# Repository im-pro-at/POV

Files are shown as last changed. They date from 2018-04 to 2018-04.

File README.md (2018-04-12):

# POV
A 131*131*12bit 16FPS POV Display

Youtube Video:

Youtube Video (http://www.youtube.com/watch?v=CScyjsmp5GI "POV")

3D Animation:

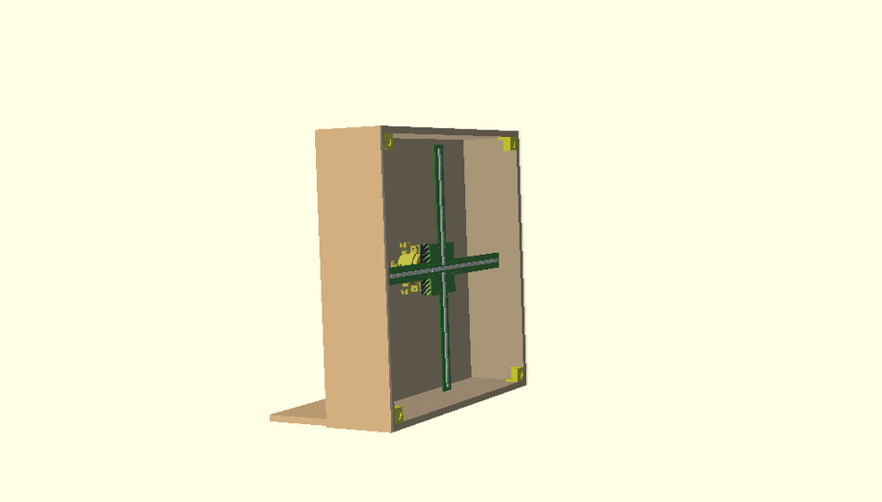
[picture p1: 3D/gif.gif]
3d


More Information: [Webside](https://im-pro.at/index.php/projekte/2018-pov)

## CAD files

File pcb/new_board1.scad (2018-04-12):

module new_board1(){
	board_thickness = 1.600000;
	eta = 0.1;
	board_size = [66.040000,71.120000,board_thickness];
	fn = 18;
	board_origin = [0.000000,0.000000];
	union(){
		color("green")difference(){
			translate(board_origin)cube(board_size); //Board
			translate([25.400,43.180,-0.1])cylinder(r=1.600000, h=board_thickness+0.2,$fn=fn); //Hole
			translate([40.640,43.180,-0.1])cylinder(r=1.600000, h=board_thickness+0.2,$fn=fn); //Hole
			translate([40.640,27.940,-0.1])cylinder(r=1.600000, h=board_thickness+0.2,$fn=fn); //Hole
			translate([25.400,27.940,-0.1])cylinder(r=1.600000, h=board_thickness+0.2,$fn=fn); //Hole
			translate([60.960,43.180,-0.1])cylinder(r=1.600000, h=board_thickness+0.2,$fn=fn); //Hole
			translate([60.960,27.940,-0.1])cylinder(r=1.600000, h=board_thickness+0.2,$fn=fn); //Hole
			translate([5.080,43.180,-0.1])cylinder(r=1.600000, h=board_thickness+0.2,$fn=fn); //Hole
			translate([5.080,27.940,-0.1])cylinder(r=1.600000, h=board_thickness+0.2,$fn=fn); //Hole
			translate([25.400,5.080,-0.1])cylinder(r=1.600000, h=board_thickness+0.2,$fn=fn); //Hole
			translate([40.640,5.080,-0.1])cylinder(r=1.600000, h=board_thickness+0.2,$fn=fn); //Hole
			translate([25.400,66.040,-0.1])cylinder(r=1.600000, h=board_thickness+0.2,$fn=fn); //Hole
			translate([40.640,66.040,-0.1])cylinder(r=1.600000, h=board_thickness+0.2,$fn=fn); //Hole
			translate([50.800,20.320,-eta])cylinder(r=0.508000, h=board_thickness+eta*2,$fn=fn); //317TS 1
			translate([53.340,20.320,-eta])cylinder(r=0.508000, h=board_thickness+eta*2,$fn=fn); //317TS 2
			translate([55.880,20.320,-eta])cylinder(r=0.508000, h=board_thickness+eta*2,$fn=fn); //317TS 3
			translate([51.435,68.580,-eta])cylinder(r=0.457200, h=board_thickness+eta*2,$fn=fn); //06P 1
			translate([53.975,68.580,-eta])cylinder(r=0.457200, h=board_thickness+eta*2,$fn=fn); //06P 2
			translate([56.515,68.580,-eta])cylinder(r=0.457200, h=board_thickness+eta*2,$fn=fn); //06P 3
			translate([59.055,68.580,-eta])cylinder(r=0.457200, h=board_thickness+eta*2,$fn=fn); //06P 4
			translate([61.595,68.580,-eta])cylinder(r=0.457200, h=board_thickness+eta*2,$fn=fn); //06P 5
			translate([64.135,68.580,-eta])cylinder(r=0.457200, h=board_thickness+eta*2,$fn=fn); //06P 6
			translate([45.720,17.780,-eta])cylinder(r=0.457200, h=board_thickness+eta*2,$fn=fn); //02P 1
			translate([45.720,20.320,-eta])cylinder(r=0.457200, h=board_thickness+eta*2,$fn=fn); //02P 2
			translate([45.720,15.240,-eta])cylinder(r=0.406400, h=board_thickness+eta*2,$fn=fn); //DCDC GND1
			translate([45.720,12.700,-eta])cylinder(r=0.406400, h=board_thickness+eta*2,$fn=fn); //DCDC GND2
			translate([64.120,15.240,-eta])cylinder(r=0.406400, h=board_thickness+eta*2,$fn=fn); //DCDC GND3
			translate([64.120,12.700,-eta])cylinder(r=0.406400, h=board_thickness+eta*2,$fn=fn); //DCDC GND4
			translate([45.720,4.640,-eta])cylinder(r=0.406400, h=board_thickness+eta*2,$fn=fn); //DCDC VIN1
			translate([45.720,2.140,-eta])cylinder(r=0.406400, h=board_thickness+eta*2,$fn=fn); //DCDC VIN2
			translate([64.120,4.640,-eta])cylinder(r=0.406400, h=board_thickness+eta*2,$fn=fn); //DCDC VOUT1
			translate([64.120,2.140,-eta])cylinder(r=0.406400, h=board_thickness+eta*2,$fn=fn); //DCDC VOUT2
			translate([20.320,2.540,-eta])cylinder(r=0.406400, h=board_thickness+eta*2,$fn=fn); //DCDC GND1
			translate([20.320,5.080,-eta])cylinder(r=0.406400, h=board_thickness+eta*2,$fn=fn); //DCDC GND2
			translate([1.920,2.540,-eta])cylinder(r=0.406400, h=board_thickness+eta*2,$fn=fn); //DCDC GND3
			translate([1.920,5.080,-eta])cylinder(r=0.406400, h=board_thickness+eta*2,$fn=fn); //DCDC GND4
			translate([20.320,13.140,-eta])cylinder(r=0.406400, h=board_thickness+eta*2,$fn=fn); //DCDC VIN1
			translate([20.320,15.640,-eta])cylinder(r=0.406400, h=board_thickness+eta*2,$fn=fn); //DCDC VIN2
			translate([1.920,13.140,-eta])cylinder(r=0.406400, h=board_thickness+eta*2,$fn=fn); //DCDC VOUT1
			translate([1.920,15.640,-eta])cylinder(r=0.406400, h=board_thickness+eta*2,$fn=fn); //DCDC VOUT2
		}
		translate([6.350,5.080,0])rotate([0,0,270])153CLV_0605();  //C1 
		translate([62.230,17.780,0])C1206();  //C2 
		translate([45.720,53.340,0])C1206();  //C3 
		translate([62.230,12.700,0])rotate([0,0,90])C1206();  //C5 
		translate([13.970,15.240,0])rotate([0,0,90])153CLV_0605();  //C6 
		translate([13.970,5.080,0])rotate([0,0,270])153CLV_0605();  //C7 
		translate([58.420,13.970,0])rotate([0,0,270])153CLV_0405();  //C8 
		translate([59.690,5.080,0])rotate([0,0,90])153CLV_0605();  //C69 
		translate([6.350,15.240,0])rotate([0,0,90])153CLV_0605();  //C71 
		translate([52.070,5.080,0])rotate([0,0,90])153CLV_0605();  //C72 
		translate([53.340,17.780,0])317TS();  //IC1 
		translate([63.460,35.560,0])rotate([0,0,270])APA102();  //LED27 APA102
		translate([58.420,35.560,0])rotate([0,0,270])APA102();  //LED28 APA102
		translate([53.340,35.560,0])rotate([0,0,270])APA102();  //LED29 APA102
		translate([48.260,35.560,0])rotate([0,0,270])APA102();  //LED30 APA102
		translate([43.180,35.560,0])rotate([0,0,270])APA102();  //LED31 APA102
		translate([38.100,35.560,0])rotate([0,0,270])APA102();  //LED32 APA102
		translate([33.020,35.560,0])rotate([0,0,270])APA102();  //LED33 APA102
		translate([33.020,2.580,0])rotate([0,0,180])APA102();  //LED60 APA102
		translate([33.020,7.620,0])rotate([0,0,180])APA102();  //LED61 APA102
		translate([33.020,12.700,0])rotate([0,0,180])APA102();  //LED62 APA102
		translate([33.020,17.780,0])rotate([0,0,180])APA102();  //LED63 APA102
		translate([33.020,22.860,0])rotate([0,0,180])APA102();  //LED64 APA102
		translate([33.020,27.940,0])rotate([0,0,180])APA102();  //LED65 APA102
		translate([2.580,35.560,0])rotate([0,0,90])APA102();  //LED92 APA102
		translate([7.620,35.560,0])rotate([0,0,90])APA102();  //LED93 APA102
		translate([12.700,35.560,0])rotate([0,0,90])APA102();  //LED94 APA102
		translate([17.780,35.560,0])rotate([0,0,90])APA102();  //LED95 APA102
		translate([22.860,35.560,0])rotate([0,0,90])APA102();  //LED96 APA102
		translate([27.940,35.560,0])rotate([0,0,90])APA102();  //LED97 APA102
		translate([33.020,68.540,0])APA102();  //LED124 APA102
		translate([33.020,63.500,0])APA102();  //LED125 APA102
		translate([33.020,58.420,0])APA102();  //LED126 APA102
		translate([33.020,53.340,0])APA102();  //LED127 APA102
		translate([33.020,48.260,0])APA102();  //LED128 APA102
		translate([33.020,43.180,0])APA102();  //LED129 APA102
		translate([45.720,62.230,0])rotate([0,0,180])M1206();  //R49 10k
		translate([45.720,50.800,0])M1206();  //R50 10k
		translate([45.720,55.880,0])rotate([0,0,180])M1206();  //R51 10k
		translate([45.720,59.055,0])rotate([0,0,180])M1206();  //R52 10k
		translate([54.610,13.970,0])rotate([0,0,270])M1206();  //R53 120R
		translate([48.260,13.970,0])rotate([0,0,270])M1206();  //R55 390R
		translate([51.435,13.970,0])rotate([0,0,90])M1206();  //R56 120R
		translate([57.785,68.580,0])06P();  //SL1 
		translate([45.720,19.050,0])rotate([0,0,90])02P();  //SL2 
		translate([58.420,56.515,0])rotate([0,0,270])ESP07_16PIN();  //U$1 ESP07-16PIN
		translate([33.020,54.610,0])rotate([0,0,180])DIL48();  //U$2 CMODS6
		translate([45.720,15.240,0])DCDC();  //U$3 DCDC
		translate([20.320,2.540,0])rotate([0,0,180])DCDC();  //U$4 DCDC
	}
}

new_board1(); //Show module
//Created by generate-scad.ulp version 0.1

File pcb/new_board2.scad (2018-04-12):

module new_board2(){
	board_thickness = 1.600000;
	eta = 0.1;
	board_size = [137.160000,22.860000,board_thickness];
	fn = 18;
	board_origin = [0.000000,0.000000];
	union(){
		color("green")difference(){
			translate(board_origin)cube(board_size); //Board
			translate([5.080,19.050,-0.1])cylinder(r=1.600000, h=board_thickness+0.2,$fn=fn); //Hole
			translate([5.080,3.810,-0.1])cylinder(r=1.600000, h=board_thickness+0.2,$fn=fn); //Hole
			translate([134.366,8.890,-eta])cylinder(r=0.457200, h=board_thickness+eta*2,$fn=fn); //03P 1
			translate([134.366,11.430,-eta])cylinder(r=0.457200, h=board_thickness+eta*2,$fn=fn); //03P 2
			translate([134.366,13.970,-eta])cylinder(r=0.457200, h=board_thickness+eta*2,$fn=fn); //03P 3
		}
		translate([83.820,11.430,0])rotate([0,0,270])C1206();  //C9 
		translate([88.900,11.430,0])rotate([0,0,270])C1206();  //C10 
		translate([93.980,11.430,0])rotate([0,0,270])C1206();  //C11 
		translate([99.060,11.430,0])rotate([0,0,270])C1206();  //C12 
		translate([104.140,11.430,0])rotate([0,0,270])C1206();  //C13 
		translate([109.220,11.430,0])rotate([0,0,270])C1206();  //C14 
		translate([114.300,11.430,0])rotate([0,0,270])C1206();  //C15 
		translate([119.380,11.430,0])rotate([0,0,270])C1206();  //C16 
		translate([12.700,11.430,0])rotate([0,0,270])C1206();  //C19 
		translate([17.780,11.430,0])rotate([0,0,270])C1206();  //C20 
		translate([22.860,11.430,0])rotate([0,0,270])C1206();  //C21 
		translate([27.940,11.430,0])rotate([0,0,270])C1206();  //C22 
		translate([33.020,11.430,0])rotate([0,0,270])C1206();  //C23 
		translate([38.100,11.430,0])rotate([0,0,270])C1206();  //C24 
		translate([43.180,11.430,0])rotate([0,0,270])C1206();  //C25 
		translate([48.260,11.430,0])rotate([0,0,270])C1206();  //C26 
		translate([53.340,11.430,0])rotate([0,0,270])C1206();  //C27 
		translate([58.420,11.430,0])rotate([0,0,270])C1206();  //C28 
		translate([63.500,11.430,0])rotate([0,0,270])C1206();  //C29 
		translate([78.740,11.430,0])rotate([0,0,270])C1206();  //C30 
		translate([129.540,11.430,0])rotate([0,0,270])APA102();  //LED1 APA102
		translate([124.460,11.430,0])rotate([0,0,270])APA102();  //LED2 APA102
		translate([119.380,11.430,0])rotate([0,0,270])APA102();  //LED3 APA102
		translate([114.300,11.430,0])rotate([0,0,270])APA102();  //LED4 APA102
		translate([109.220,11.430,0])rotate([0,0,270])APA102();  //LED5 APA102
		translate([104.140,11.430,0])rotate([0,0,270])APA102();  //LED6 APA102
		translate([99.060,11.430,0])rotate([0,0,270])APA102();  //LED7 APA102
		translate([93.980,11.430,0])rotate([0,0,270])APA102();  //LED8 APA102
		translate([88.900,11.430,0])rotate([0,0,270])APA102();  //LED9 APA102
		translate([83.820,11.430,0])rotate([0,0,270])APA102();  //LED10 APA102
		translate([78.740,11.430,0])rotate([0,0,270])APA102();  //LED11 APA102
		translate([73.660,11.430,0])rotate([0,0,270])APA102();  //LED12 APA102
		translate([68.580,11.430,0])rotate([0,0,270])APA102();  //LED13 APA102
		translate([63.500,11.430,0])rotate([0,0,270])APA102();  //LED14 APA102
		translate([58.420,11.430,0])rotate([0,0,270])APA102();  //LED15 APA102
		translate([53.340,11.430,0])rotate([0,0,270])APA102();  //LED16 APA102
		translate([48.260,11.430,0])rotate([0,0,270])APA102();  //LED17 APA102
		translate([43.180,11.430,0])rotate([0,0,270])APA102();  //LED18 APA102
		translate([38.100,11.430,0])rotate([0,0,270])APA102();  //LED19 APA102
		translate([33.020,11.430,0])rotate([0,0,270])APA102();  //LED20 APA102
		translate([27.940,11.430,0])rotate([0,0,270])APA102();  //LED21 APA102
		translate([22.860,11.430,0])rotate([0,0,270])APA102();  //LED22 APA102
		translate([17.780,11.430,0])rotate([0,0,270])APA102();  //LED23 APA102
		translate([12.700,11.430,0])rotate([0,0,270])APA102();  //LED24 APA102
		translate([7.620,11.430,0])rotate([0,0,270])APA102();  //LED25 APA102
		translate([2.580,11.430,0])rotate([0,0,270])APA102();  //LED26 APA102
		translate([134.366,11.430,0])rotate([0,0,90])03P();  //SL3 
		translate([127.000,11.430,0])SO014();  //U$9 74HCT125D
		translate([71.120,11.430,0])SO014();  //U$10 74HCT125D
	}
}

new_board2(); //Show module
//Created by generate-scad.ulp version 0.1

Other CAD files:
3D/config.scad
3D/motor.scad
3D/brush.scad
3D/corner.scad
3D/holder.scad
3D/magnete.scad
3D/main.scad
3D/pcb.scad

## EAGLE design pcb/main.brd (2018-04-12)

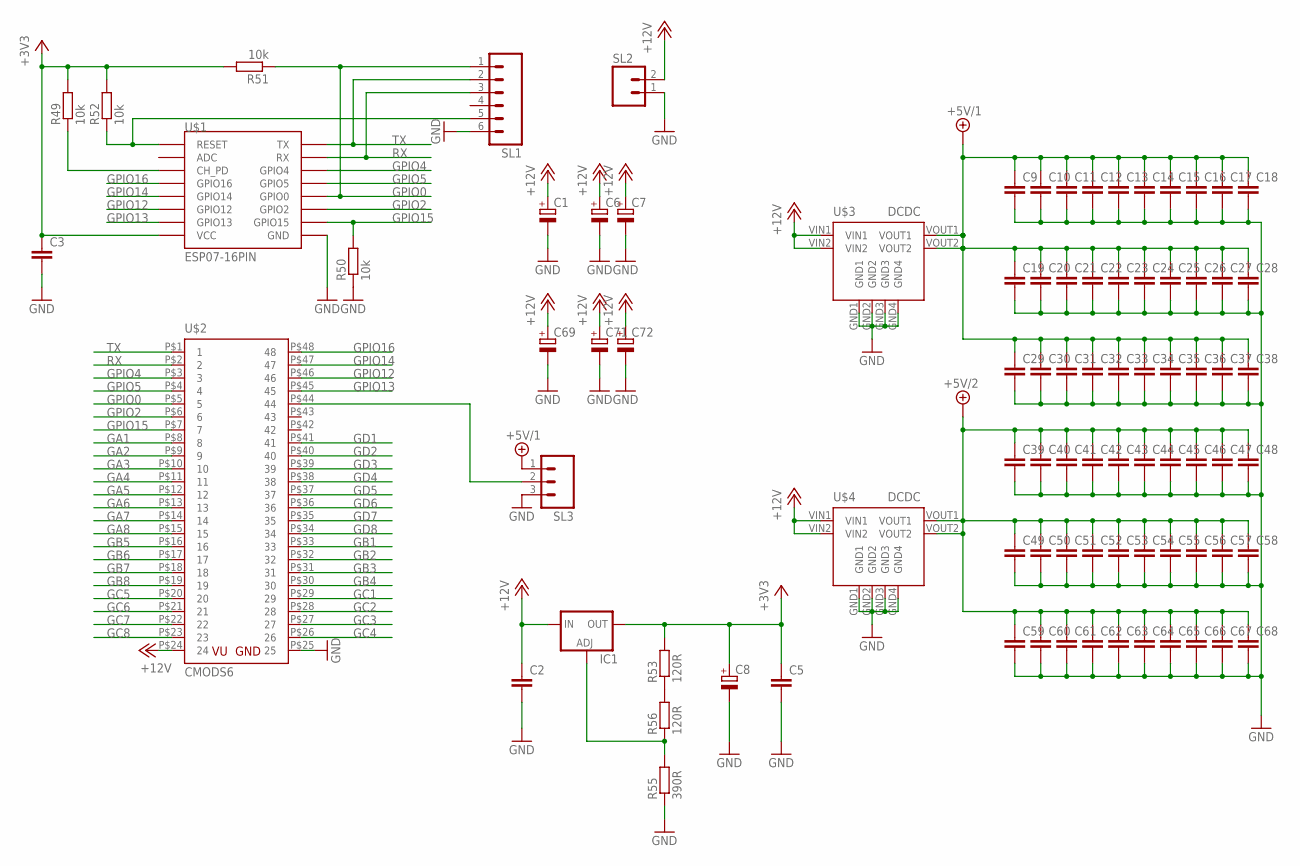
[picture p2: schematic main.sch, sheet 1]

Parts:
C1, C6, C7, C69, C71, C72: CPOL-EU153CLV-0605; 153CLV-0605
C2, C3, C5, C9, C10, C11, C12, C13, C14, C15, C16, C17, C18, C19, C20, C21, C22, C23, C24, C25, C26, C27, C28, C29, C30, C31, C32, C33, C34, C35, C36, C37, C38, C39, C40, C41, C42, C43, C44, C45, C46, C47, C48, C49, C50, C51, C52, C53, C54, C55, C56, C57, C58, C59, C60, C61, C62, C63, C64, C65, C66, C67, C68: C-EUC1206; C1206
C8: CPOL-EU153CLV-0405; 153CLV-0405
IC1: LM317TS; 317TS
R49, R50, R51, R52: 10k; M1206
R53, R56: 120R; M1206
R55: 390R; M1206
SL1: M06; 06P
SL2: M02; 02P
SL3: M03; 03P
U$1: ESP07-16PIN
U$2: CMODS6; DIL48
U$3, U$4: DCDC

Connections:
+3V3: C3.1, C5.1, C8.+, IC1.2 (OUT), R49.2, R51.2, R52.2, R53.2, U$1.VCC
+5V/1: C9.1, C10.1, C11.1, C12.1, C13.1, C14.1, C15.1, C16.1, C17.1, C18.1, C19.1, C20.1, C21.1, C22.1, C23.1, C24.1, C25.1, C26.1, C27.1, C28.1, C29.1, C30.1, C31.1, C32.1, C33.1, C34.1, C35.1, C36.1, C37.1, C38.1, SL3.1, U$3.VOUT1, U$3.VOUT2; also elsewhere on the board
+5V/2: C39.1, C40.1, C41.1, C42.1, C43.1, C44.1, C45.1, C46.1, C47.1, C48.1, C49.1, C50.1, C51.1, C52.1, C53.1, C54.1, C55.1, C56.1, C57.1, C58.1, C59.1, C60.1, C61.1, C62.1, C63.1, C64.1, C65.1, C66.1, C67.1, C68.1, U$4.VOUT1, U$4.VOUT2; also elsewhere on the board
+12V: C1.+, C2.1, C6.+, C7.+, C69.+, C71.+, C72.+, IC1.3 (IN), SL2.2, U$2.P$24 (24), U$3.VIN1, U$3.VIN2, U$4.VIN1, U$4.VIN2
GA1: U$2.P$8 (8); also elsewhere on the board
GA2: U$2.P$9 (9); also elsewhere on the board
GA3: U$2.P$10 (10); also elsewhere on the board
GA4: U$2.P$11 (11); also elsewhere on the board
GA5: U$2.P$12 (12); also elsewhere on the board
GA6: U$2.P$13 (13); also elsewhere on the board
GA7: U$2.P$14 (14); also elsewhere on the board
GA8: U$2.P$15 (15); also elsewhere on the board
GB1: U$2.P$33 (33); also elsewhere on the board
GB2: U$2.P$32 (32); also elsewhere on the board
GB3: U$2.P$31 (31); also elsewhere on the board
GB4: U$2.P$30 (30); also elsewhere on the board
GB5: U$2.P$16 (16); also elsewhere on the board
GB6: U$2.P$17 (17); also elsewhere on the board
GB7: U$2.P$18 (18); also elsewhere on the board
GB8: U$2.P$19 (19); also elsewhere on the board
GC1: U$2.P$29 (29); also elsewhere on the board
GC2: U$2.P$28 (28); also elsewhere on the board
GC3: U$2.P$27 (27); also elsewhere on the board
GC4: U$2.P$26 (26); also elsewhere on the board
GC5: U$2.P$20 (20); also elsewhere on the board
GC6: U$2.P$21 (21); also elsewhere on the board
GC7: U$2.P$22 (22); also elsewhere on the board
GC8: U$2.P$23 (23); also elsewhere on the board
GD1: U$2.P$41 (41); also elsewhere on the board
GD2: U$2.P$40 (40); also elsewhere on the board
GD3: U$2.P$39 (39); also elsewhere on the board
GD4: U$2.P$38 (38); also elsewhere on the board
GD5: U$2.P$37 (37); also elsewhere on the board
GD6: U$2.P$36 (36); also elsewhere on the board
GD7: U$2.P$35 (35); also elsewhere on the board
GD8: U$2.P$34 (34); also elsewhere on the board
GND: C1.-, C2.2, C3.2, C5.2, C6.-, C7.-, C8.-, C9.2, C10.2, C11.2, C12.2, C13.2, C14.2, C15.2, C16.2, C17.2, C18.2, C19.2, C20.2, C21.2, C22.2, C23.2, C24.2, C25.2, C26.2, C27.2, C28.2, C29.2, C30.2, C31.2, C32.2, C33.2, C34.2, C35.2, C36.2, C37.2, C38.2, C39.2, C40.2, C41.2, C42.2, C43.2, C44.2, C45.2, C46.2, C47.2, C48.2, C49.2, C50.2, C51.2, C52.2, C53.2, C54.2, C55.2, C56.2, C57.2, C58.2, C59.2, C60.2, C61.2, C62.2, C63.2, C64.2, C65.2, C66.2, C67.2, C68.2, C69.-, C71.-, C72.-, R50.1, R55.1, SL1.6, SL2.1, SL3.3, U$1.GND, U$2.P$25 (25), U$3.GND1, U$3.GND2, U$3.GND3, U$3.GND4, U$4.GND1, U$4.GND2, U$4.GND3, U$4.GND4; also elsewhere on the board
GPIO0: R51.1, SL1.1, U$1.GPIO0, U$2.P$5 (5)
GPIO2: U$1.GPIO2, U$2.P$6 (6)
GPIO4: U$1.GPIO4, U$2.P$3 (3)
GPIO5: U$1.GPIO5, U$2.P$4 (4)
GPIO12: U$1.GPIO12, U$2.P$46 (46)
GPIO13: U$1.GPIO13, U$2.P$45 (45)
GPIO14: U$1.GPIO14, U$2.P$47 (47)
GPIO15: R50.2, U$1.GPIO15, U$2.P$7 (7)
GPIO16: U$1.GPIO16, U$2.P$48 (48)
unnamed: SL3.2, U$2.P$44 (44)
unnamed: R52.1, SL1.5, U$1.REST (RESET)
unnamed: R49.1, U$1.CH_PD
unnamed: IC1.1 (ADJ), R55.2, R56.1
unnamed: R53.1, R56.2
RX: SL1.3, U$1.RX, U$2.P$2 (2)
TX: SL1.2, U$1.TX, U$2.P$1 (1)

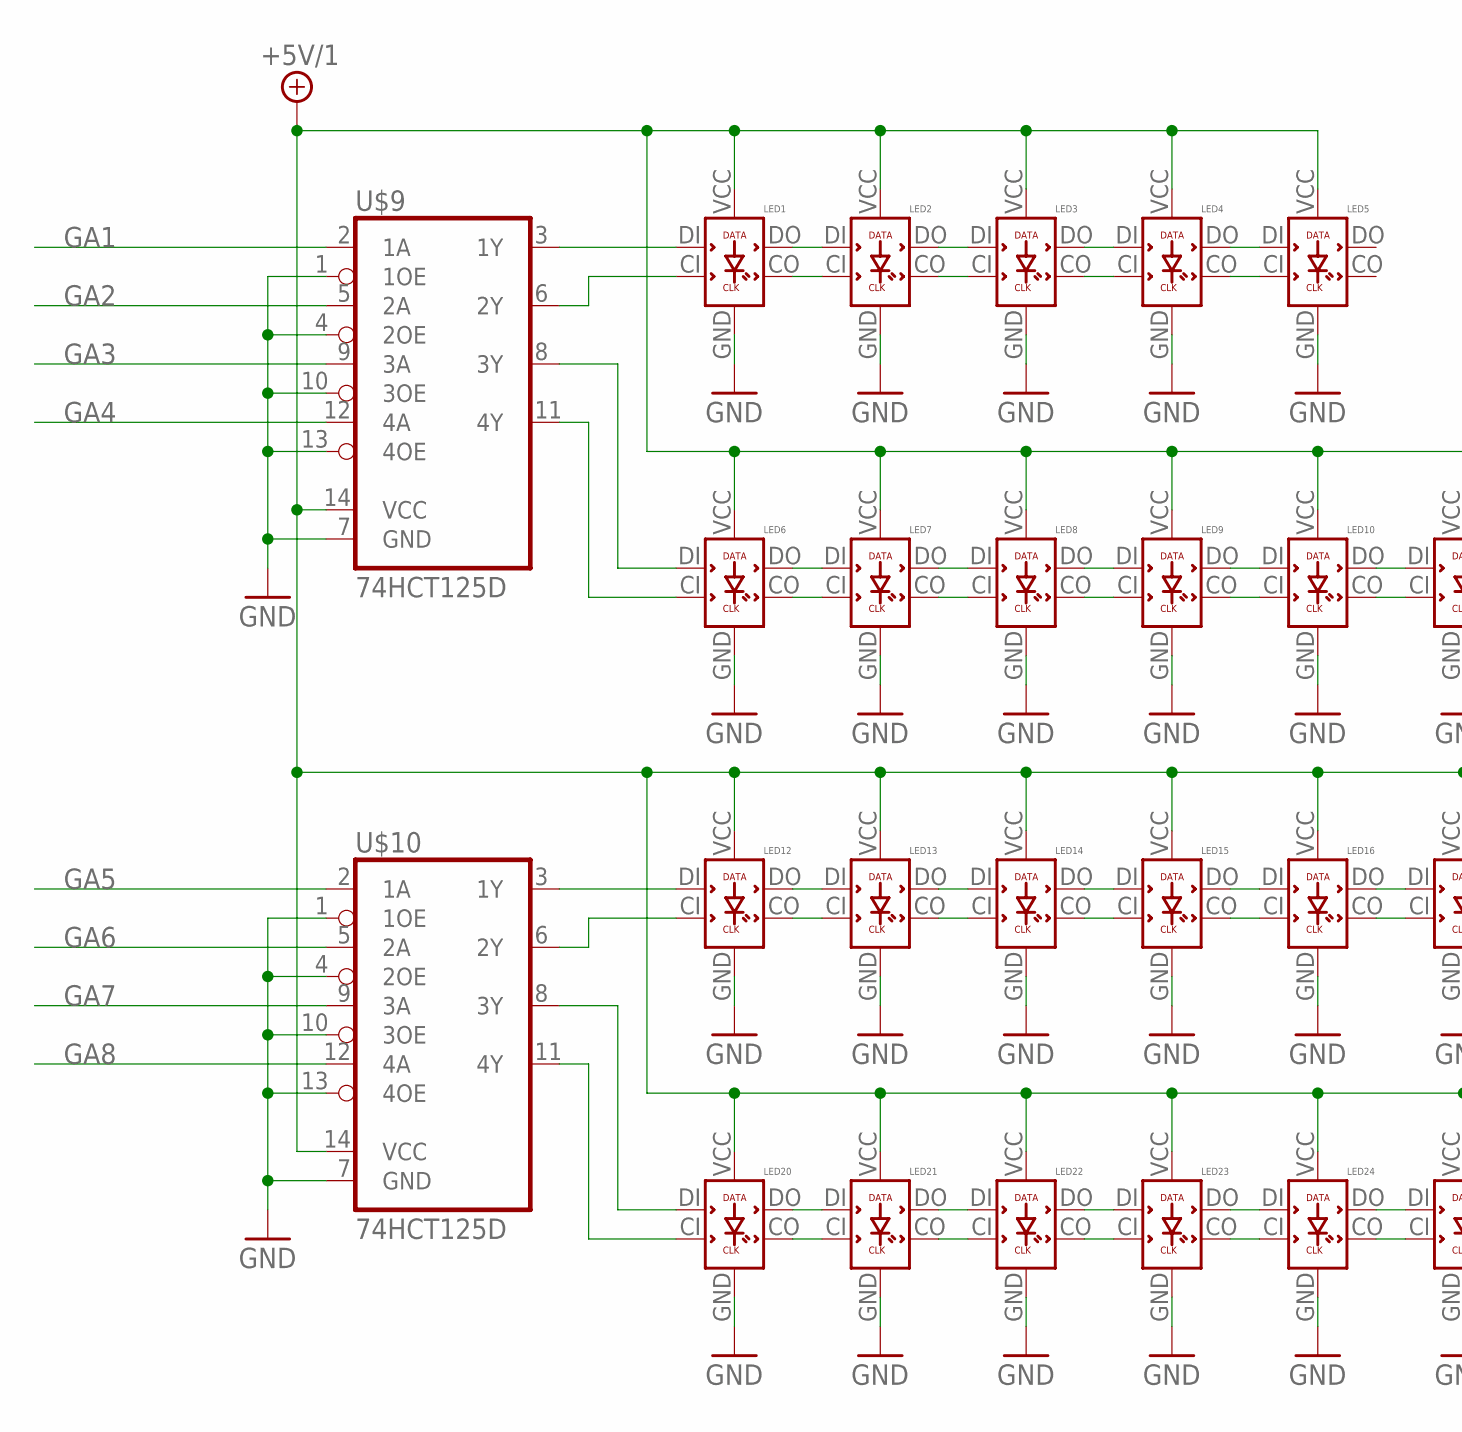
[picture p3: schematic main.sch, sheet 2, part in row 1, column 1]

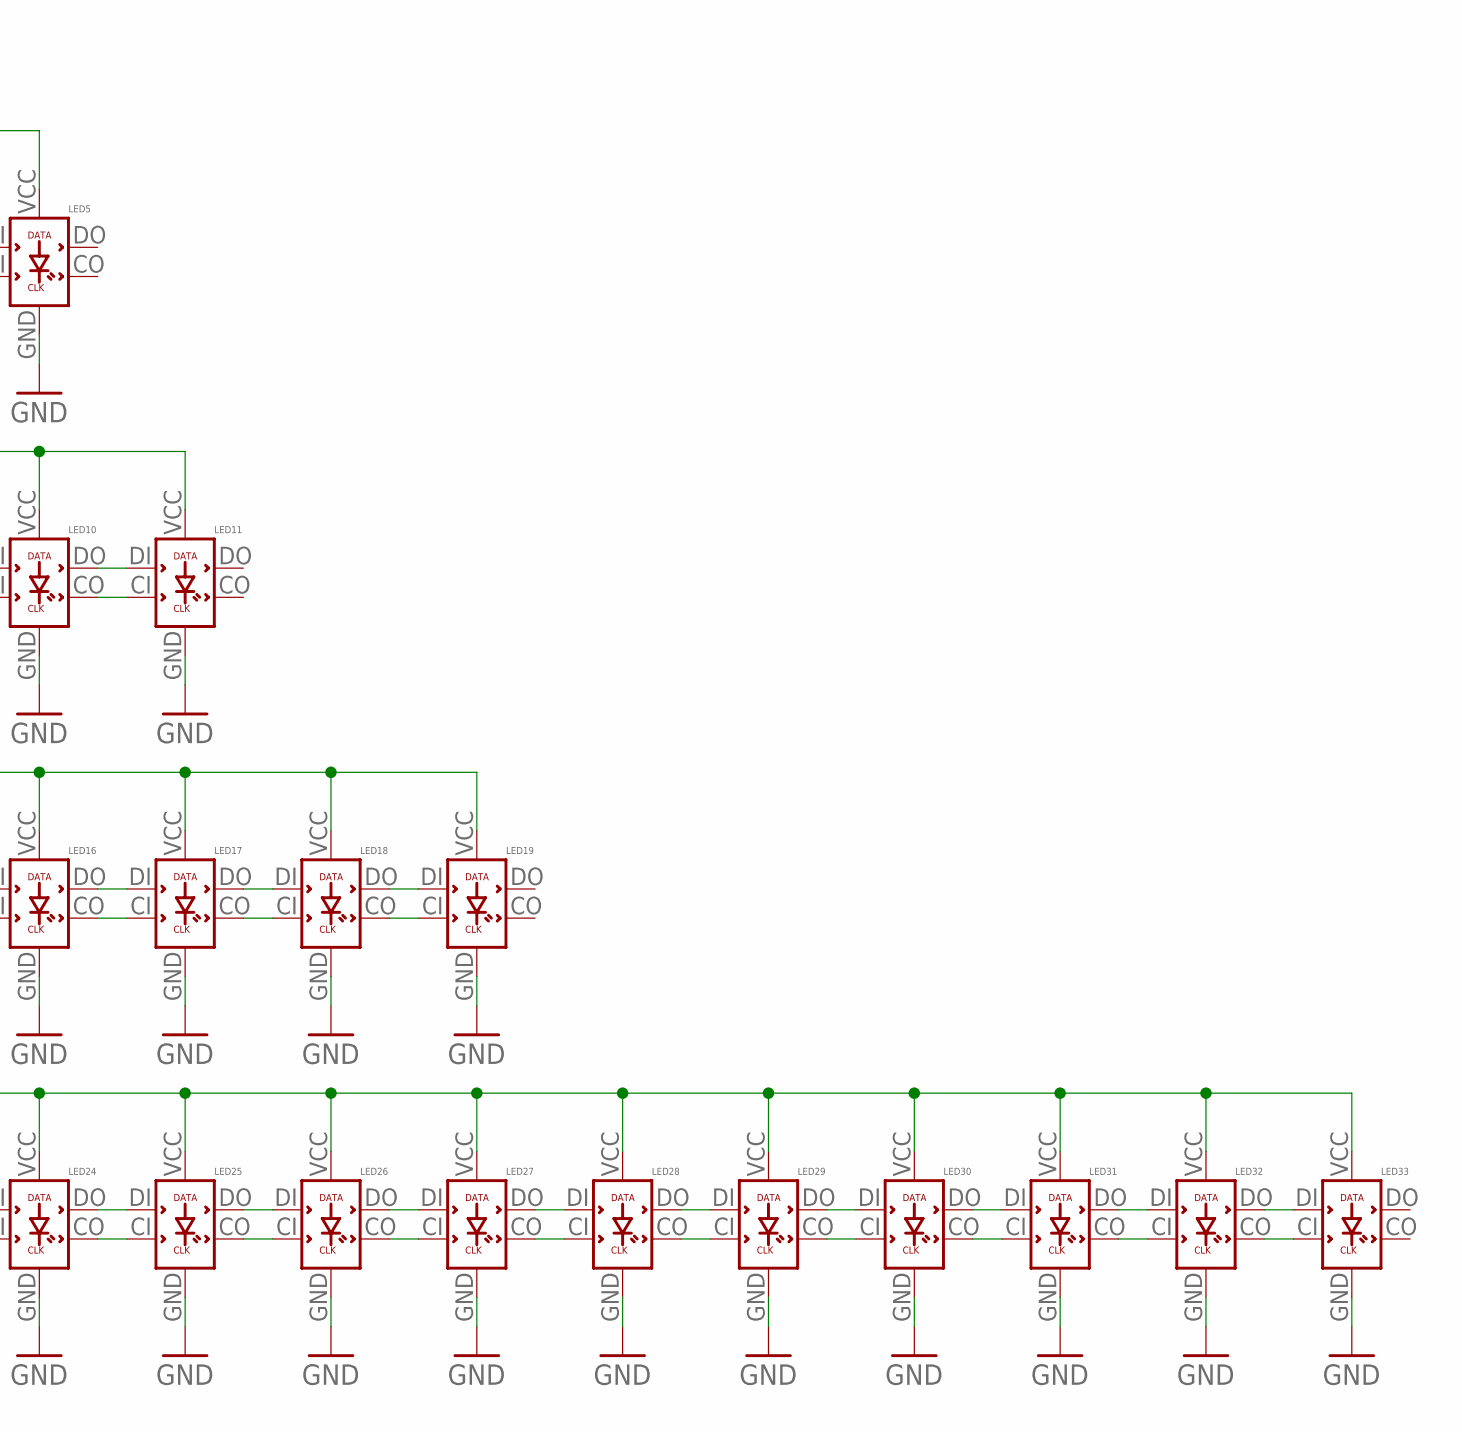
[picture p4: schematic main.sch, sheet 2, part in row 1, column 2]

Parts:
LED1, LED2, LED3, LED4, LED5, LED6, LED7, LED8, LED9, LED10, LED11, LED12, LED13, LED14, LED15, LED16, LED17, LED18, LED19, LED20, LED21, LED22, LED23, LED24, LED25, LED26, LED27, LED28, LED29, LED30, LED31, LED32, LED33: APA102
U$9, U$10: 74HCT125D; SO014

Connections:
+5V/1: LED1.VCC, LED2.VCC, LED3.VCC, LED4.VCC, LED5.VCC, LED6.VCC, LED7.VCC, LED8.VCC, LED9.VCC, LED10.VCC, LED11.VCC, LED12.VCC, LED13.VCC, LED14.VCC, LED15.VCC, LED16.VCC, LED17.VCC, LED18.VCC, LED19.VCC, LED20.VCC, LED21.VCC, LED22.VCC, LED23.VCC, LED24.VCC, LED25.VCC, LED26.VCC, LED27.VCC, LED28.VCC, LED29.VCC, LED30.VCC, LED31.VCC, LED32.VCC, LED33.VCC, U$9.14 (VCC), U$10.14 (VCC); also elsewhere on the board
GA1: U$9.2 (1A); also elsewhere on the board
GA2: U$9.5 (2A); also elsewhere on the board
GA3: U$9.9 (3A); also elsewhere on the board
GA4: U$9.12 (4A); also elsewhere on the board
GA5: U$10.2 (1A); also elsewhere on the board
GA6: U$10.5 (2A); also elsewhere on the board
GA7: U$10.9 (3A); also elsewhere on the board
GA8: U$10.12 (4A); also elsewhere on the board
GND: LED1.GND, LED2.GND, LED3.GND, LED4.GND, LED5.GND, LED6.GND, LED7.GND, LED8.GND, LED9.GND, LED10.GND, LED11.GND, LED12.GND, LED13.GND, LED14.GND, LED15.GND, LED16.GND, LED17.GND, LED18.GND, LED19.GND, LED20.GND, LED21.GND, LED22.GND, LED23.GND, LED24.GND, LED25.GND, LED26.GND, LED27.GND, LED28.GND, LED29.GND, LED30.GND, LED31.GND, LED32.GND, LED33.GND, U$9.1 (1OE), U$9.4 (2OE), U$9.7 (GND), U$9.10 (3OE), U$9.13 (4OE), U$10.1 (1OE), U$10.4 (2OE), U$10.7 (GND), U$10.10 (3OE), U$10.13 (4OE); also elsewhere on the board
unnamed: LED2.DO, LED3.DI
unnamed: LED2.CO, LED3.CI
unnamed: LED3.DO, LED4.DI
unnamed: LED3.CO, LED4.CI
unnamed: LED4.DO, LED5.DI
unnamed: LED4.CO, LED5.CI
unnamed: LED1.DO, LED2.DI
unnamed: LED1.CO, LED2.CI
unnamed: LED7.DO, LED8.DI
unnamed: LED7.CO, LED8.CI
unnamed: LED8.DO, LED9.DI
unnamed: LED8.CO, LED9.CI
unnamed: LED9.DO, LED10.DI
unnamed: LED9.CO, LED10.CI
unnamed: LED6.DO, LED7.DI
unnamed: LED6.CO, LED7.CI
unnamed: LED10.DO, LED11.DI
unnamed: LED10.CO, LED11.CI
unnamed: LED21.DO, LED22.DI
unnamed: LED13.DO, LED14.DI
unnamed: LED13.CO, LED14.CI
unnamed: LED14.DO, LED15.DI
unnamed: LED14.CO, LED15.CI
unnamed: LED15.DO, LED16.DI
unnamed: LED15.CO, LED16.CI
unnamed: LED12.DO, LED13.DI
unnamed: LED12.CO, LED13.CI
unnamed: LED16.DO, LED17.DI
unnamed: LED16.CO, LED17.CI
unnamed: LED21.CO, LED22.CI
unnamed: LED17.DO, LED18.DI
unnamed: LED17.CO, LED18.CI
unnamed: LED22.DO, LED23.DI
unnamed: LED18.DO, LED19.DI
unnamed: LED18.CO, LED19.CI
unnamed: LED22.CO, LED23.CI
unnamed: LED23.DO, LED24.DI
unnamed: LED23.CO, LED24.CI
unnamed: LED20.DO, LED21.DI
unnamed: LED20.CO, LED21.CI
unnamed: LED24.DO, LED25.DI
unnamed: LED24.CO, LED25.CI
unnamed: LED25.DO, LED26.DI
unnamed: LED25.CO, LED26.CI
unnamed: LED26.DO, LED27.DI
unnamed: LED26.CO, LED27.CI
unnamed: LED27.DO, LED28.DI
unnamed: LED27.CO, LED28.CI
unnamed: LED28.DO, LED29.DI
unnamed: LED28.CO, LED29.CI
unnamed: LED29.DO, LED30.DI
unnamed: LED29.CO, LED30.CI
unnamed: LED1.DI, U$9.3 (1Y)
unnamed: LED30.DO, LED31.DI
unnamed: LED30.CO, LED31.CI
unnamed: LED31.DO, LED32.DI
unnamed: LED31.CO, LED32.CI
unnamed: LED32.DO, LED33.DI
unnamed: LED32.CO, LED33.CI
unnamed: LED1.CI, U$9.6 (2Y)
unnamed: LED6.DI, U$9.8 (3Y)
unnamed: LED6.CI, U$9.11 (4Y)
unnamed: LED12.DI, U$10.3 (1Y)
unnamed: LED12.CI, U$10.6 (2Y)
unnamed: LED20.DI, U$10.8 (3Y)
unnamed: LED20.CI, U$10.11 (4Y)

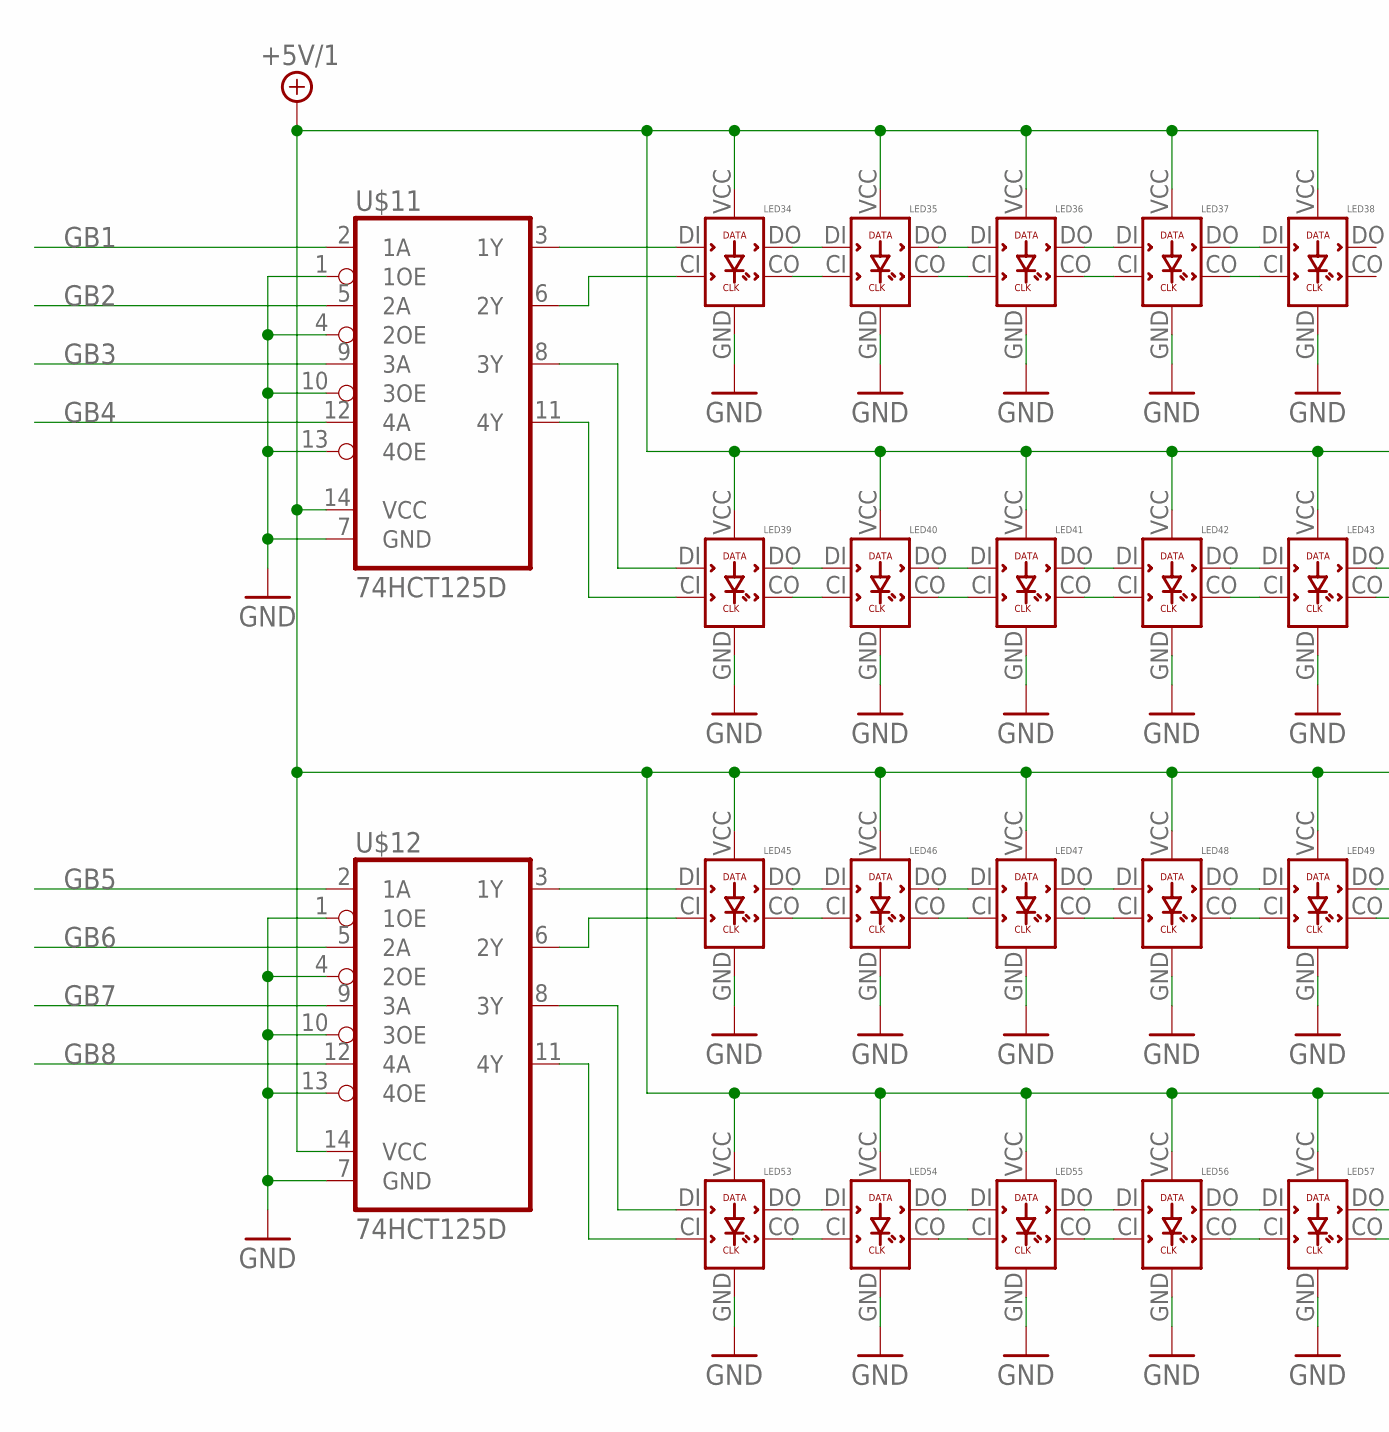
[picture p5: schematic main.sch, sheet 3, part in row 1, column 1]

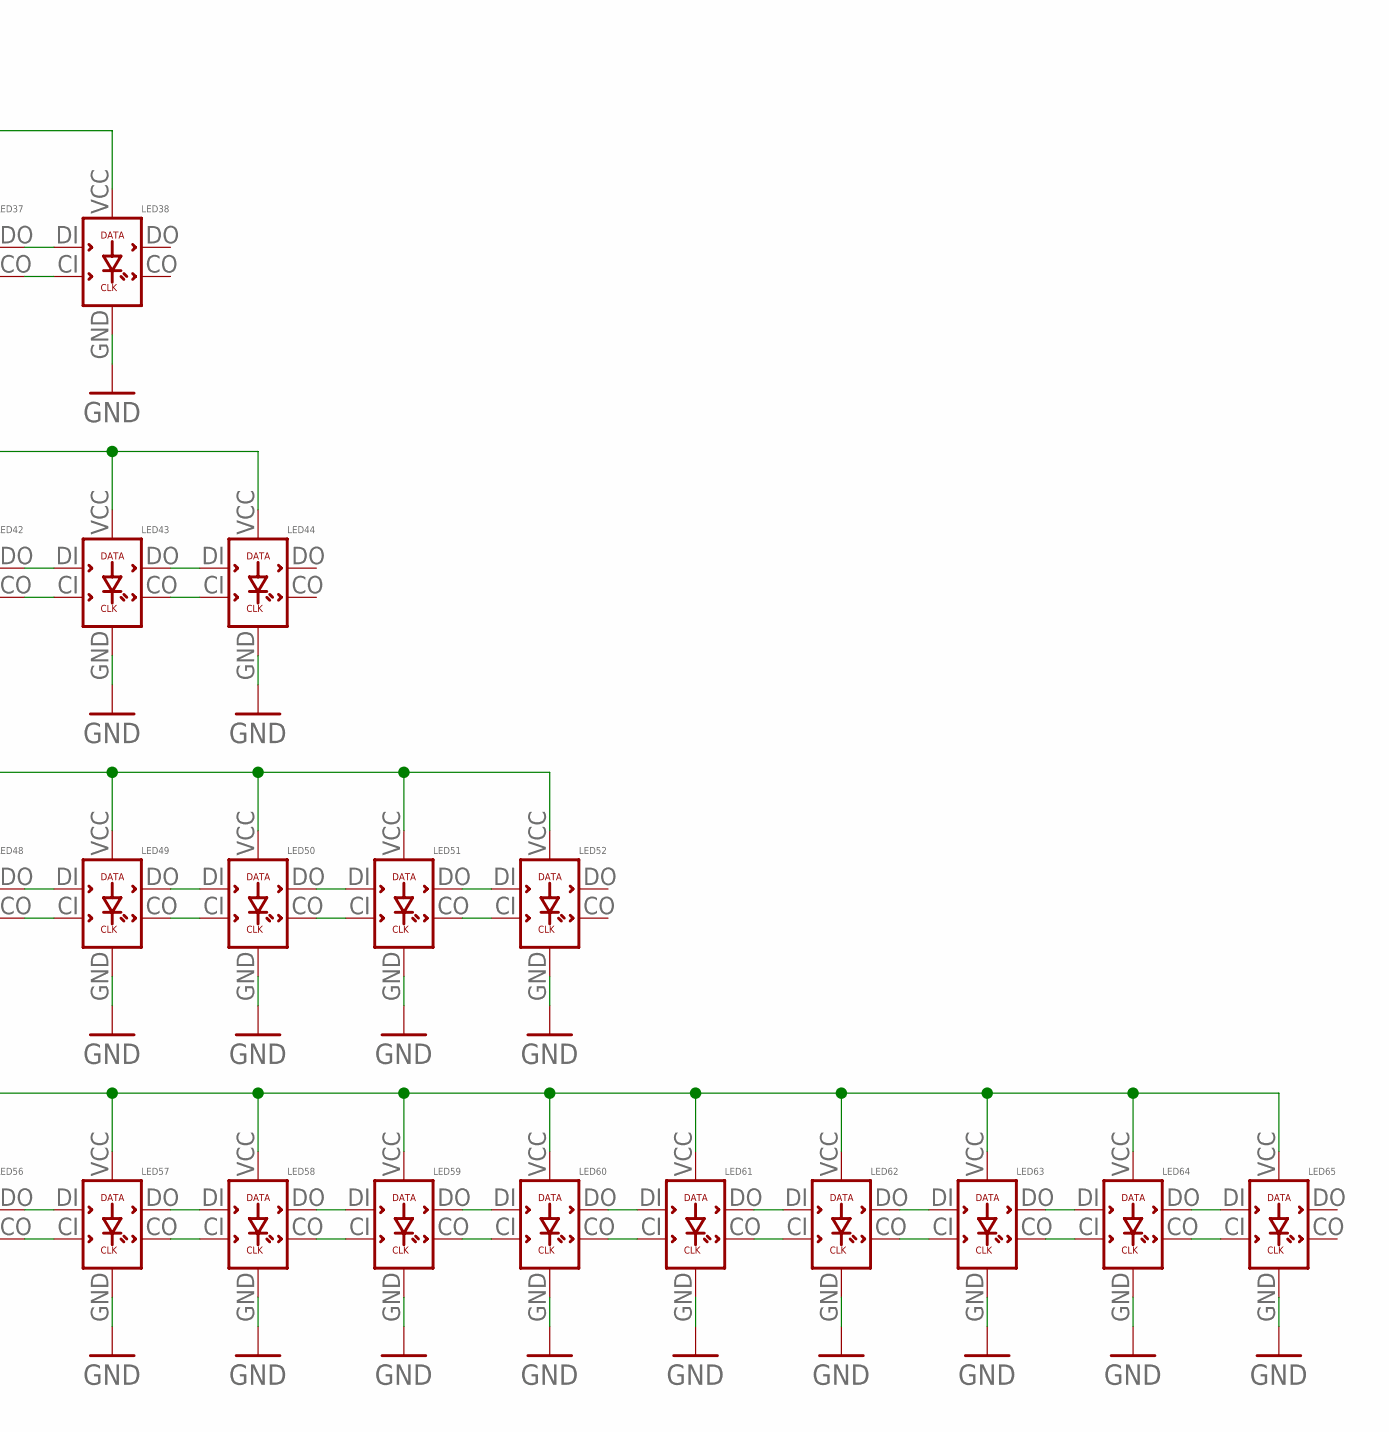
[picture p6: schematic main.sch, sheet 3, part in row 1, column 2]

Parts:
LED34, LED35, LED36, LED37, LED38, LED39, LED40, LED41, LED42, LED43, LED44, LED45, LED46, LED47, LED48, LED49, LED50, LED51, LED52, LED53, LED54, LED55, LED56, LED57, LED58, LED59, LED60, LED61, LED62, LED63, LED64, LED65: APA102
U$11, U$12: 74HCT125D; SO014

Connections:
+5V/1: LED34.VCC, LED35.VCC, LED36.VCC, LED37.VCC, LED38.VCC, LED39.VCC, LED40.VCC, LED41.VCC, LED42.VCC, LED43.VCC, LED44.VCC, LED45.VCC, LED46.VCC, LED47.VCC, LED48.VCC, LED49.VCC, LED50.VCC, LED51.VCC, LED52.VCC, LED53.VCC, LED54.VCC, LED55.VCC, LED56.VCC, LED57.VCC, LED58.VCC, LED59.VCC, LED60.VCC, LED61.VCC, LED62.VCC, LED63.VCC, LED64.VCC, LED65.VCC, U$11.14 (VCC), U$12.14 (VCC); also elsewhere on the board
GB1: U$11.2 (1A); also elsewhere on the board
GB2: U$11.5 (2A); also elsewhere on the board
GB3: U$11.9 (3A); also elsewhere on the board
GB4: U$11.12 (4A); also elsewhere on the board
GB5: U$12.2 (1A); also elsewhere on the board
GB6: U$12.5 (2A); also elsewhere on the board
GB7: U$12.9 (3A); also elsewhere on the board
GB8: U$12.12 (4A); also elsewhere on the board
GND: LED34.GND, LED35.GND, LED36.GND, LED37.GND, LED38.GND, LED39.GND, LED40.GND, LED41.GND, LED42.GND, LED43.GND, LED44.GND, LED45.GND, LED46.GND, LED47.GND, LED48.GND, LED49.GND, LED50.GND, LED51.GND, LED52.GND, LED53.GND, LED54.GND, LED55.GND, LED56.GND, LED57.GND, LED58.GND, LED59.GND, LED60.GND, LED61.GND, LED62.GND, LED63.GND, LED64.GND, LED65.GND, U$11.1 (1OE), U$11.4 (2OE), U$11.7 (GND), U$11.10 (3OE), U$11.13 (4OE), U$12.1 (1OE), U$12.4 (2OE), U$12.7 (GND), U$12.10 (3OE), U$12.13 (4OE); also elsewhere on the board
unnamed: LED35.DO, LED36.DI
unnamed: LED35.CO, LED36.CI
unnamed: LED36.DO, LED37.DI
unnamed: LED36.CO, LED37.CI
unnamed: LED37.DO, LED38.DI
unnamed: LED37.CO, LED38.CI
unnamed: LED34.DO, LED35.DI
unnamed: LED34.CO, LED35.CI
unnamed: LED40.DO, LED41.DI
unnamed: LED40.CO, LED41.CI
unnamed: LED41.DO, LED42.DI
unnamed: LED41.CO, LED42.CI
unnamed: LED42.DO, LED43.DI
unnamed: LED42.CO, LED43.CI
unnamed: LED39.DO, LED40.DI
unnamed: LED39.CO, LED40.CI
unnamed: LED43.DO, LED44.DI
unnamed: LED43.CO, LED44.CI
unnamed: LED46.DO, LED47.DI
unnamed: LED46.CO, LED47.CI
unnamed: LED47.DO, LED48.DI
unnamed: LED47.CO, LED48.CI
unnamed: LED48.DO, LED49.DI
unnamed: LED48.CO, LED49.CI
unnamed: LED45.DO, LED46.DI
unnamed: LED45.CO, LED46.CI
unnamed: LED49.DO, LED50.DI
unnamed: LED49.CO, LED50.CI
unnamed: LED50.DO, LED51.DI
unnamed: LED50.CO, LED51.CI
unnamed: LED51.DO, LED52.DI
unnamed: LED51.CO, LED52.CI
unnamed: LED54.DO, LED55.DI
unnamed: LED54.CO, LED55.CI
unnamed: LED55.DO, LED56.DI
unnamed: LED55.CO, LED56.CI
unnamed: LED56.DO, LED57.DI
unnamed: LED56.CO, LED57.CI
unnamed: LED53.DO, LED54.DI
unnamed: LED53.CO, LED54.CI
unnamed: LED57.DO, LED58.DI
unnamed: LED57.CO, LED58.CI
unnamed: LED58.DO, LED59.DI
unnamed: LED58.CO, LED59.CI
unnamed: LED59.DO, LED60.DI
unnamed: LED59.CO, LED60.CI
unnamed: LED60.DO, LED61.DI
unnamed: LED60.CO, LED61.CI
unnamed: LED61.DO, LED62.DI
unnamed: LED61.CO, LED62.CI
unnamed: LED62.DO, LED63.DI
unnamed: LED62.CO, LED63.CI
unnamed: LED63.DO, LED64.DI
unnamed: LED63.CO, LED64.CI
unnamed: LED64.DO, LED65.DI
unnamed: LED64.CO, LED65.CI
unnamed: LED34.DI, U$11.3 (1Y)
unnamed: LED34.CI, U$11.6 (2Y)
unnamed: LED39.DI, U$11.8 (3Y)
unnamed: LED39.CI, U$11.11 (4Y)
unnamed: LED45.DI, U$12.3 (1Y)
unnamed: LED45.CI, U$12.6 (2Y)
unnamed: LED53.DI, U$12.8 (3Y)
unnamed: LED53.CI, U$12.11 (4Y)

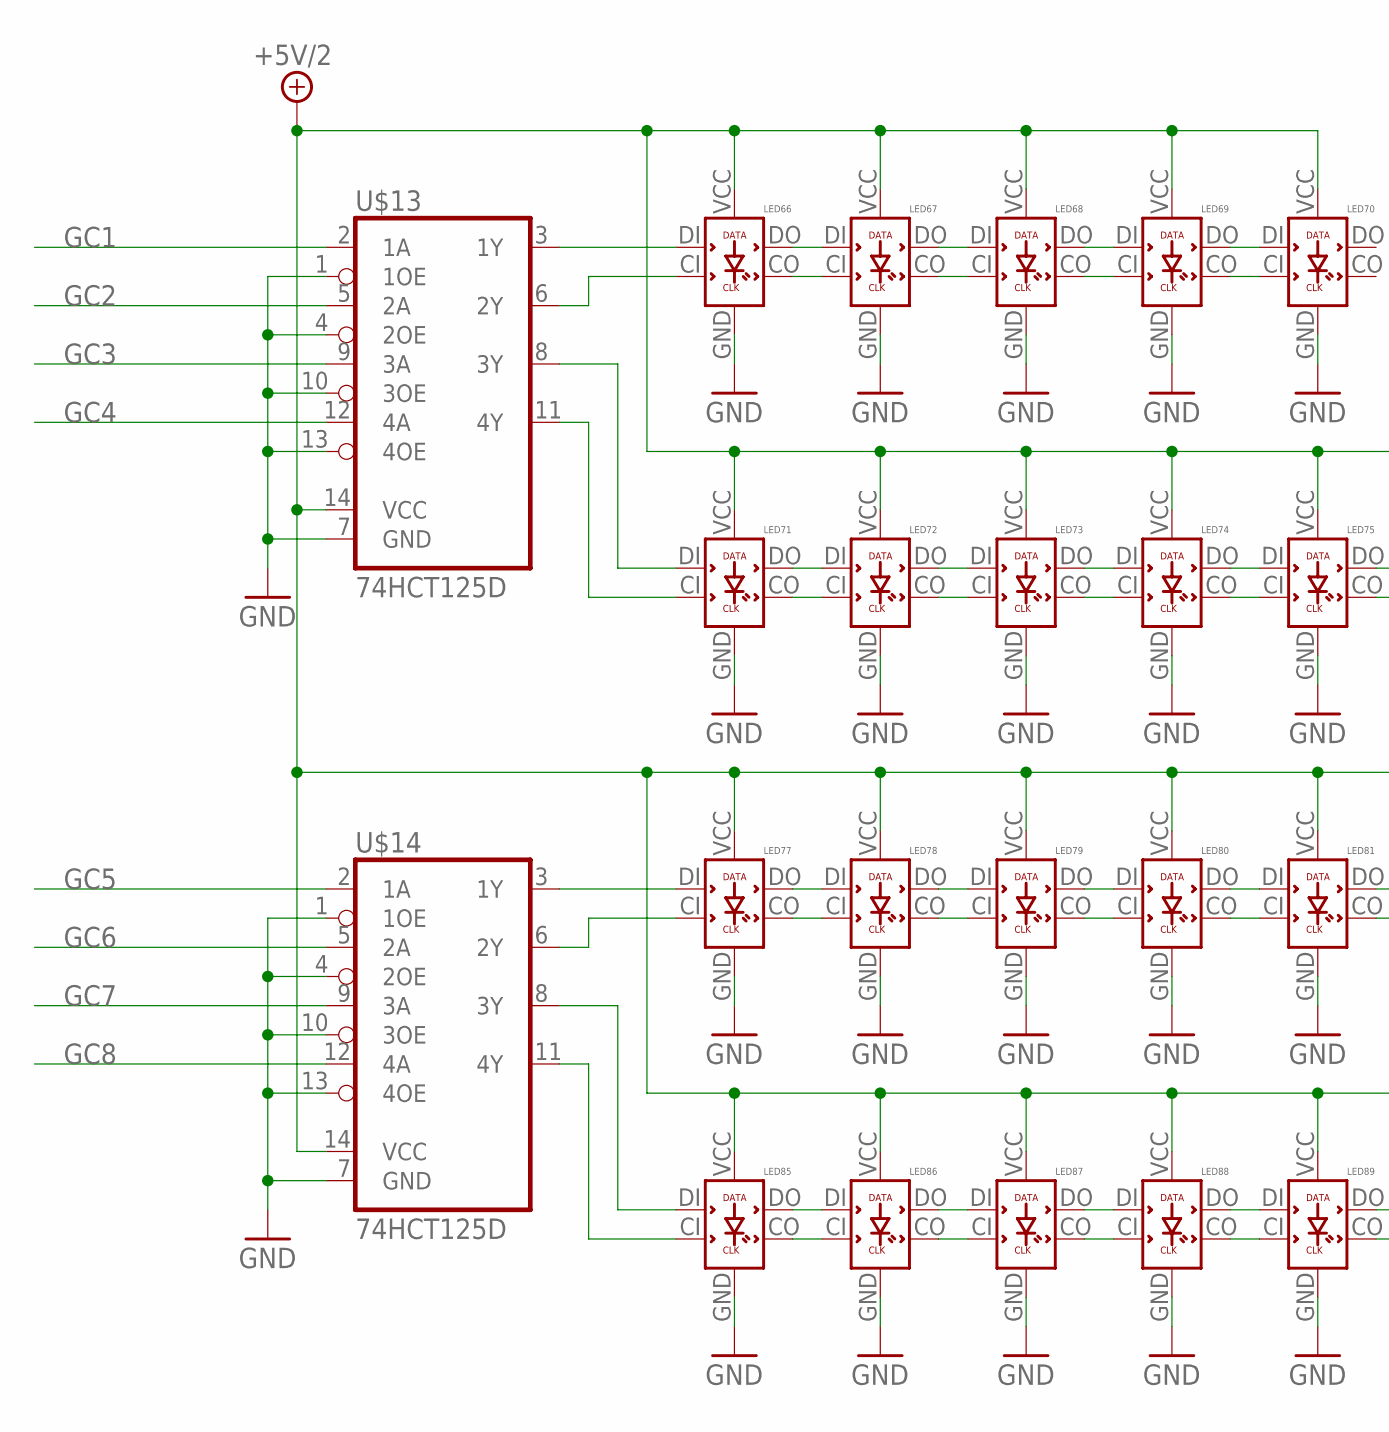
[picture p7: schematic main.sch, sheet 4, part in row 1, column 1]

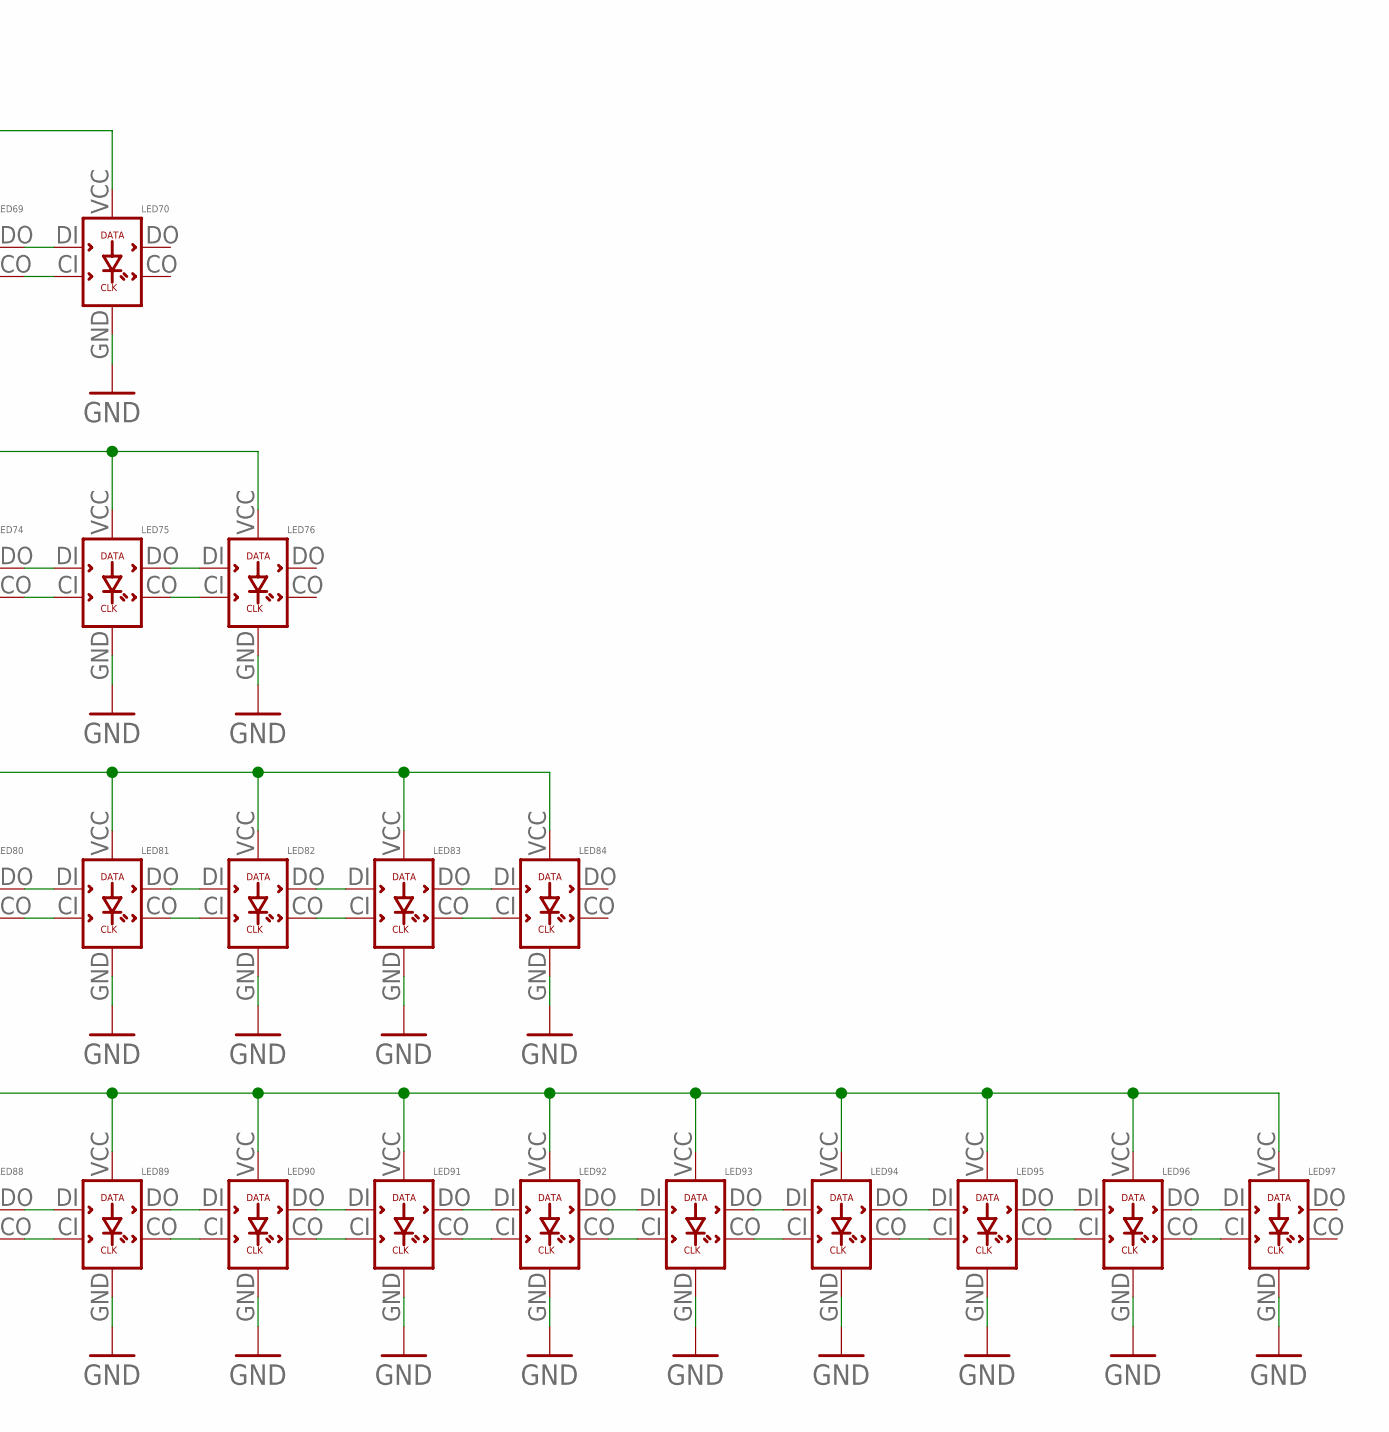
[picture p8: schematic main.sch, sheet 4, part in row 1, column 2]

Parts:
LED66, LED67, LED68, LED69, LED70, LED71, LED72, LED73, LED74, LED75, LED76, LED77, LED78, LED79, LED80, LED81, LED82, LED83, LED84, LED85, LED86, LED87, LED88, LED89, LED90, LED91, LED92, LED93, LED94, LED95, LED96, LED97: APA102
U$13, U$14: 74HCT125D; SO014

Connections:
+5V/2: LED66.VCC, LED67.VCC, LED68.VCC, LED69.VCC, LED70.VCC, LED71.VCC, LED72.VCC, LED73.VCC, LED74.VCC, LED75.VCC, LED76.VCC, LED77.VCC, LED78.VCC, LED79.VCC, LED80.VCC, LED81.VCC, LED82.VCC, LED83.VCC, LED84.VCC, LED85.VCC, LED86.VCC, LED87.VCC, LED88.VCC, LED89.VCC, LED90.VCC, LED91.VCC, LED92.VCC, LED93.VCC, LED94.VCC, LED95.VCC, LED96.VCC, LED97.VCC, U$13.14 (VCC), U$14.14 (VCC); also elsewhere on the board
GC1: U$13.2 (1A); also elsewhere on the board
GC2: U$13.5 (2A); also elsewhere on the board
GC3: U$13.9 (3A); also elsewhere on the board
GC4: U$13.12 (4A); also elsewhere on the board
GC5: U$14.2 (1A); also elsewhere on the board
GC6: U$14.5 (2A); also elsewhere on the board
GC7: U$14.9 (3A); also elsewhere on the board
GC8: U$14.12 (4A); also elsewhere on the board
GND: LED66.GND, LED67.GND, LED68.GND, LED69.GND, LED70.GND, LED71.GND, LED72.GND, LED73.GND, LED74.GND, LED75.GND, LED76.GND, LED77.GND, LED78.GND, LED79.GND, LED80.GND, LED81.GND, LED82.GND, LED83.GND, LED84.GND, LED85.GND, LED86.GND, LED87.GND, LED88.GND, LED89.GND, LED90.GND, LED91.GND, LED92.GND, LED93.GND, LED94.GND, LED95.GND, LED96.GND, LED97.GND, U$13.1 (1OE), U$13.4 (2OE), U$13.7 (GND), U$13.10 (3OE), U$13.13 (4OE), U$14.1 (1OE), U$14.4 (2OE), U$14.7 (GND), U$14.10 (3OE), U$14.13 (4OE); also elsewhere on the board
unnamed: LED67.DO, LED68.DI
unnamed: LED67.CO, LED68.CI
unnamed: LED68.DO, LED69.DI
unnamed: LED68.CO, LED69.CI
unnamed: LED69.DO, LED70.DI
unnamed: LED69.CO, LED70.CI
unnamed: LED66.DO, LED67.DI
unnamed: LED66.CO, LED67.CI
unnamed: LED72.DO, LED73.DI
unnamed: LED72.CO, LED73.CI
unnamed: LED73.DO, LED74.DI
unnamed: LED73.CO, LED74.CI
unnamed: LED74.DO, LED75.DI
unnamed: LED74.CO, LED75.CI
unnamed: LED71.DO, LED72.DI
unnamed: LED71.CO, LED72.CI
unnamed: LED75.DO, LED76.DI
unnamed: LED75.CO, LED76.CI
unnamed: LED78.DO, LED79.DI
unnamed: LED78.CO, LED79.CI
unnamed: LED79.DO, LED80.DI
unnamed: LED79.CO, LED80.CI
unnamed: LED80.DO, LED81.DI
unnamed: LED80.CO, LED81.CI
unnamed: LED77.DO, LED78.DI
unnamed: LED77.CO, LED78.CI
unnamed: LED81.DO, LED82.DI
unnamed: LED81.CO, LED82.CI
unnamed: LED82.DO, LED83.DI
unnamed: LED82.CO, LED83.CI
unnamed: LED83.DO, LED84.DI
unnamed: LED83.CO, LED84.CI
unnamed: LED86.DO, LED87.DI
unnamed: LED86.CO, LED87.CI
unnamed: LED87.DO, LED88.DI
unnamed: LED87.CO, LED88.CI
unnamed: LED88.DO, LED89.DI
unnamed: LED88.CO, LED89.CI
unnamed: LED85.DO, LED86.DI
unnamed: LED85.CO, LED86.CI
unnamed: LED89.DO, LED90.DI
unnamed: LED89.CO, LED90.CI
unnamed: LED90.DO, LED91.DI
unnamed: LED90.CO, LED91.CI
unnamed: LED91.DO, LED92.DI
unnamed: LED91.CO, LED92.CI
unnamed: LED92.DO, LED93.DI
unnamed: LED92.CO, LED93.CI
unnamed: LED93.DO, LED94.DI
unnamed: LED93.CO, LED94.CI
unnamed: LED94.DO, LED95.DI
unnamed: LED94.CO, LED95.CI
unnamed: LED95.DO, LED96.DI
unnamed: LED95.CO, LED96.CI
unnamed: LED96.DO, LED97.DI
unnamed: LED96.CO, LED97.CI
unnamed: LED66.DI, U$13.3 (1Y)
unnamed: LED66.CI, U$13.6 (2Y)
unnamed: LED71.DI, U$13.8 (3Y)
unnamed: LED71.CI, U$13.11 (4Y)
unnamed: LED77.DI, U$14.3 (1Y)
unnamed: LED77.CI, U$14.6 (2Y)
unnamed: LED85.DI, U$14.8 (3Y)
unnamed: LED85.CI, U$14.11 (4Y)

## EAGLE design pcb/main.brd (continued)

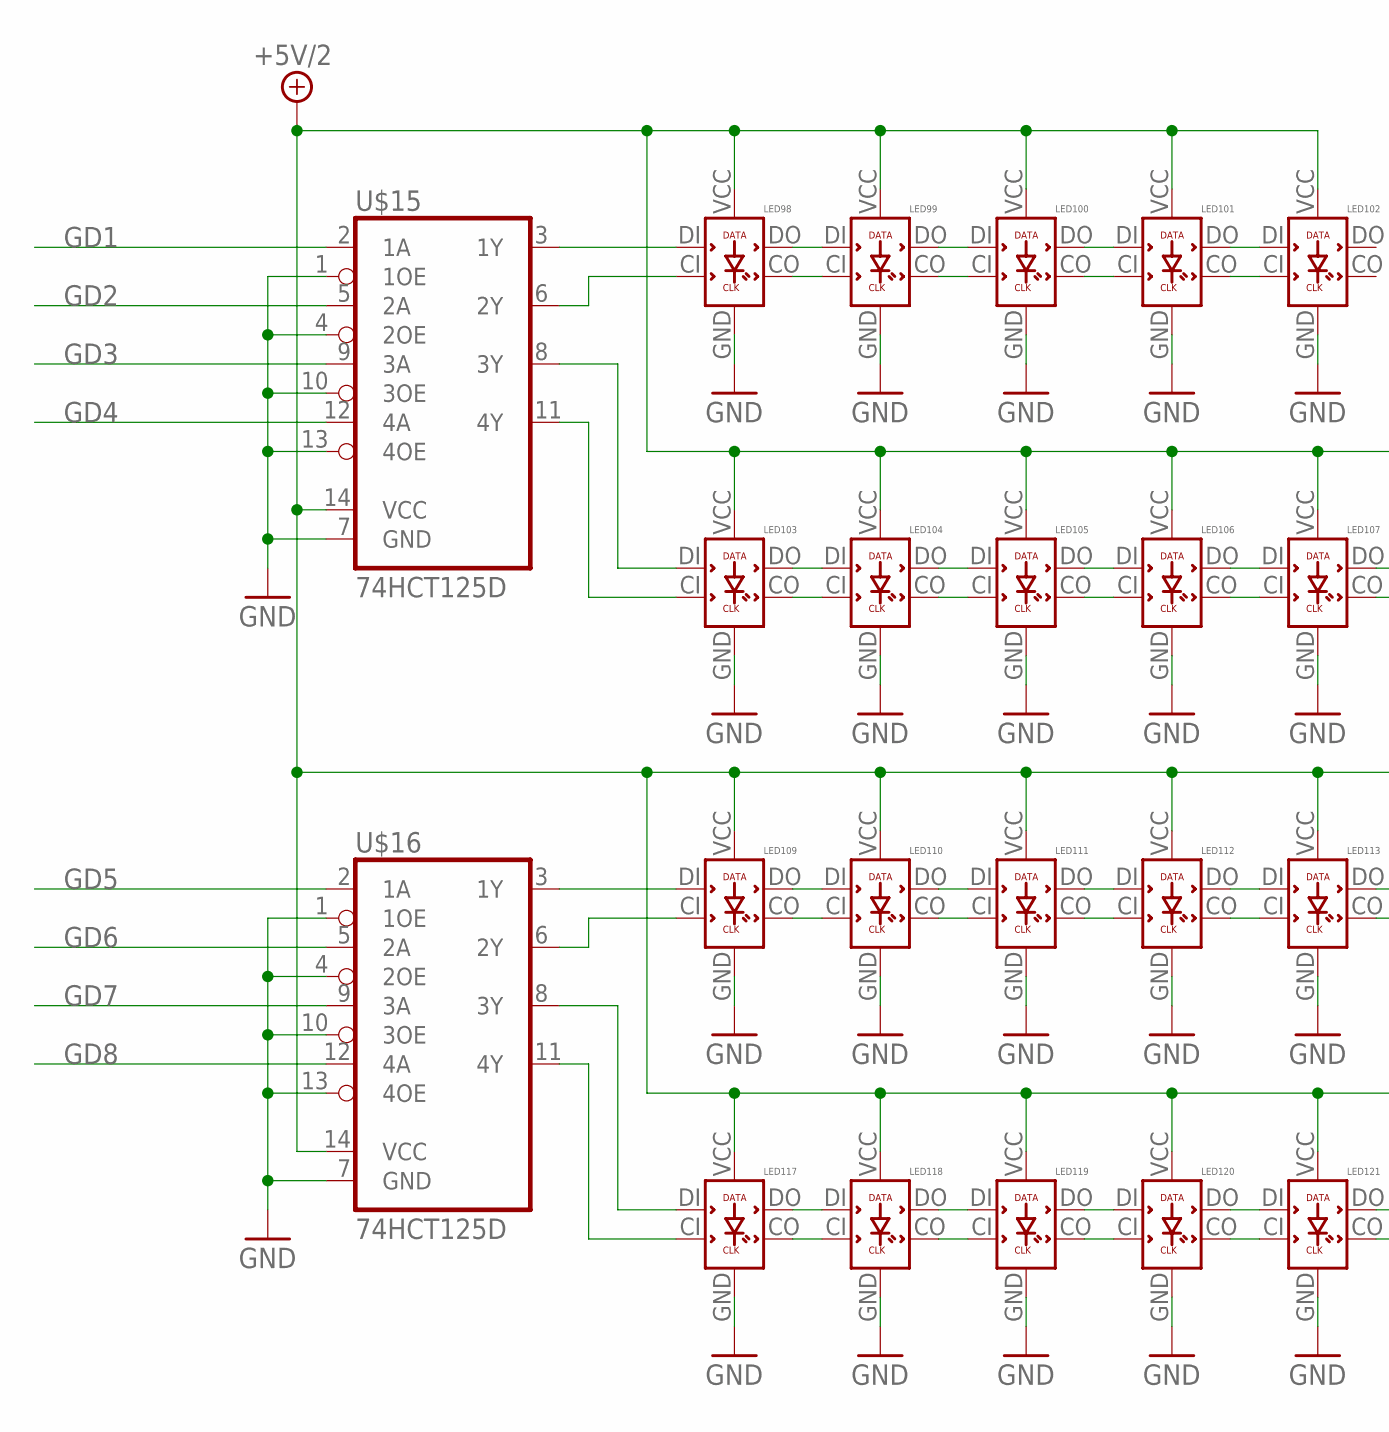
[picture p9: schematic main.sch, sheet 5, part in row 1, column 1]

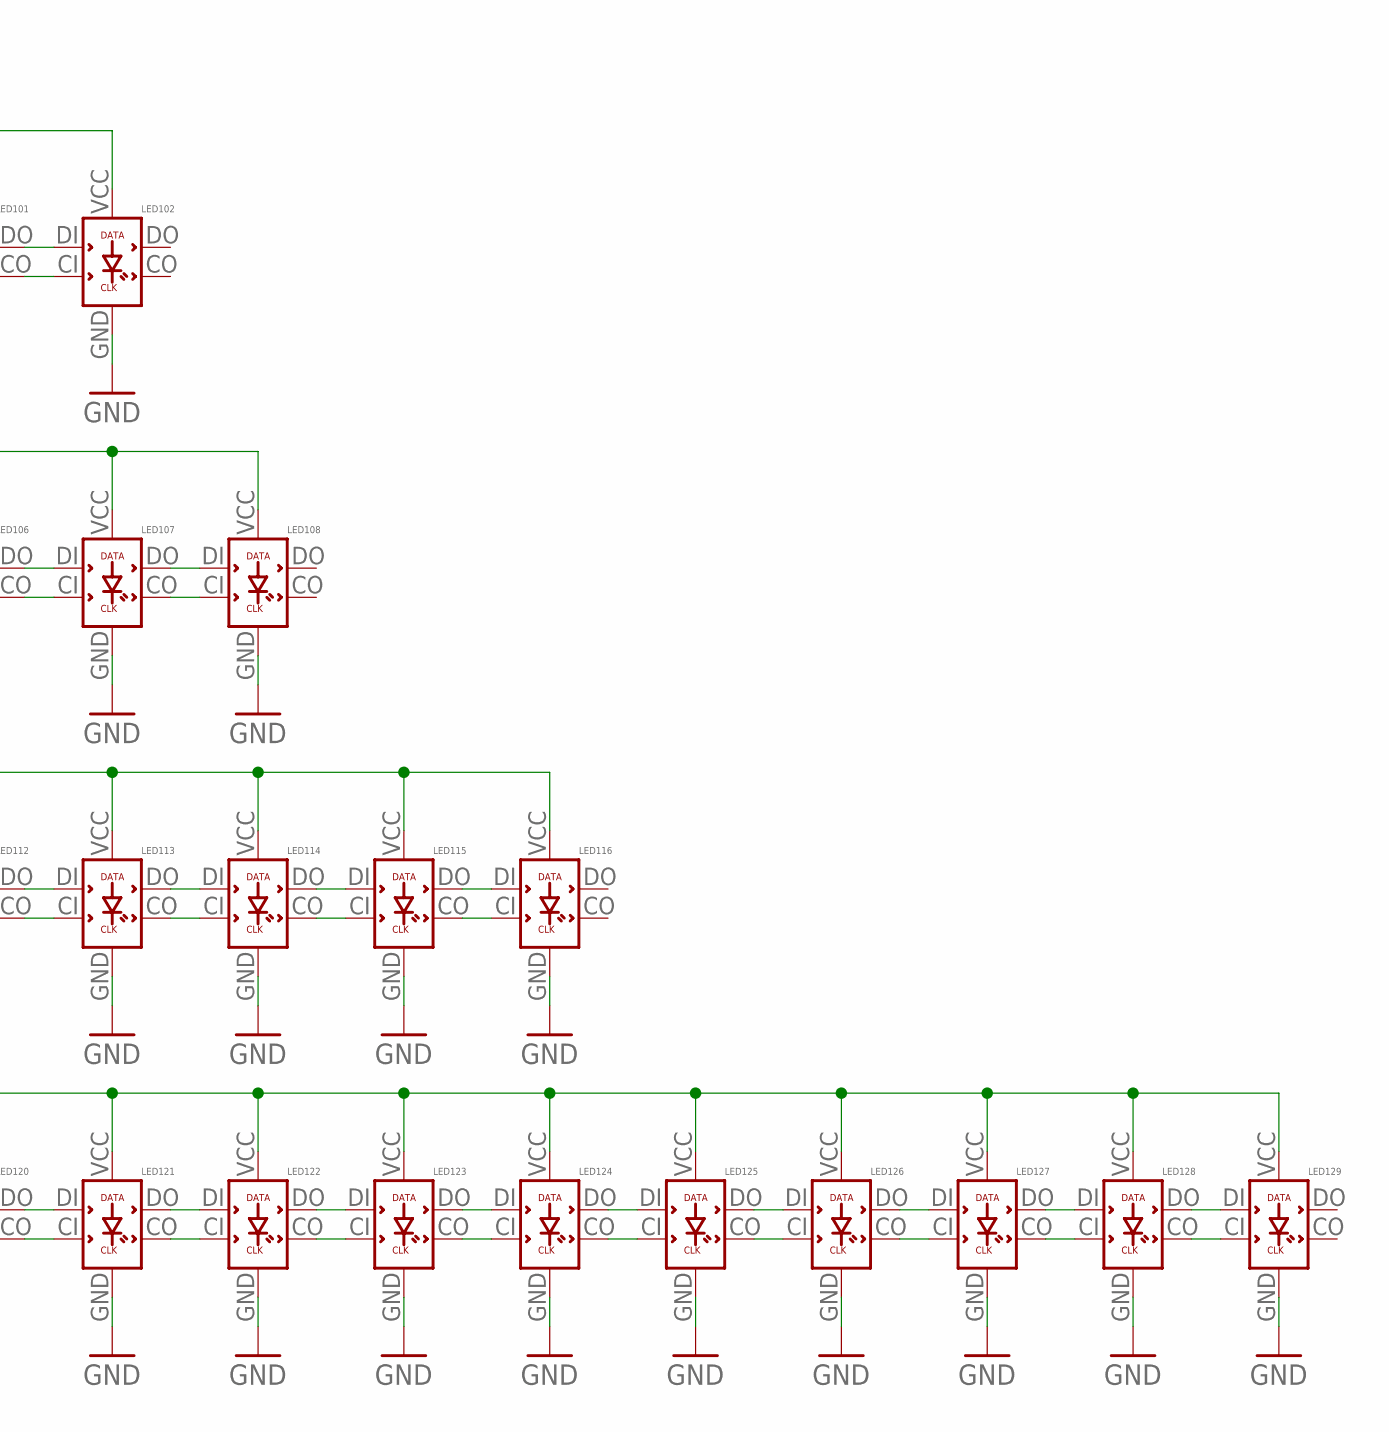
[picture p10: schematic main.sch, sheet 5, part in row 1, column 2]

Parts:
LED98, LED99, LED100, LED101, LED102, LED103, LED104, LED105, LED106, LED107, LED108, LED109, LED110, LED111, LED112, LED113, LED114, LED115, LED116, LED117, LED118, LED119, LED120, LED121, LED122, LED123, LED124, LED125, LED126, LED127, LED128, LED129: APA102
U$15, U$16: 74HCT125D; SO014

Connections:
+5V/2: LED98.VCC, LED99.VCC, LED100.VCC, LED101.VCC, LED102.VCC, LED103.VCC, LED104.VCC, LED105.VCC, LED106.VCC, LED107.VCC, LED108.VCC, LED109.VCC, LED110.VCC, LED111.VCC, LED112.VCC, LED113.VCC, LED114.VCC, LED115.VCC, LED116.VCC, LED117.VCC, LED118.VCC, LED119.VCC, LED120.VCC, LED121.VCC, LED122.VCC, LED123.VCC, LED124.VCC, LED125.VCC, LED126.VCC, LED127.VCC, LED128.VCC, LED129.VCC, U$15.14 (VCC), U$16.14 (VCC); also elsewhere on the board
GD1: U$15.2 (1A); also elsewhere on the board
GD2: U$15.5 (2A); also elsewhere on the board
GD3: U$15.9 (3A); also elsewhere on the board
GD4: U$15.12 (4A); also elsewhere on the board
GD5: U$16.2 (1A); also elsewhere on the board
GD6: U$16.5 (2A); also elsewhere on the board
GD7: U$16.9 (3A); also elsewhere on the board
GD8: U$16.12 (4A); also elsewhere on the board
GND: LED98.GND, LED99.GND, LED100.GND, LED101.GND, LED102.GND, LED103.GND, LED104.GND, LED105.GND, LED106.GND, LED107.GND, LED108.GND, LED109.GND, LED110.GND, LED111.GND, LED112.GND, LED113.GND, LED114.GND, LED115.GND, LED116.GND, LED117.GND, LED118.GND, LED119.GND, LED120.GND, LED121.GND, LED122.GND, LED123.GND, LED124.GND, LED125.GND, LED126.GND, LED127.GND, LED128.GND, LED129.GND, U$15.1 (1OE), U$15.4 (2OE), U$15.7 (GND), U$15.10 (3OE), U$15.13 (4OE), U$16.1 (1OE), U$16.4 (2OE), U$16.7 (GND), U$16.10 (3OE), U$16.13 (4OE); also elsewhere on the board
unnamed: LED99.DO, LED100.DI
unnamed: LED99.CO, LED100.CI
unnamed: LED100.DO, LED101.DI
unnamed: LED100.CO, LED101.CI
unnamed: LED101.DO, LED102.DI
unnamed: LED101.CO, LED102.CI
unnamed: LED98.DO, LED99.DI
unnamed: LED98.CO, LED99.CI
unnamed: LED104.DO, LED105.DI
unnamed: LED104.CO, LED105.CI
unnamed: LED105.DO, LED106.DI
unnamed: LED105.CO, LED106.CI
unnamed: LED106.DO, LED107.DI
unnamed: LED106.CO, LED107.CI
unnamed: LED103.DO, LED104.DI
unnamed: LED103.CO, LED104.CI
unnamed: LED107.DO, LED108.DI
unnamed: LED107.CO, LED108.CI
unnamed: LED110.DO, LED111.DI
unnamed: LED110.CO, LED111.CI
unnamed: LED111.DO, LED112.DI
unnamed: LED111.CO, LED112.CI
unnamed: LED112.DO, LED113.DI
unnamed: LED112.CO, LED113.CI
unnamed: LED109.DO, LED110.DI
unnamed: LED109.CO, LED110.CI
unnamed: LED113.DO, LED114.DI
unnamed: LED113.CO, LED114.CI
unnamed: LED114.DO, LED115.DI
unnamed: LED114.CO, LED115.CI
unnamed: LED115.DO, LED116.DI
unnamed: LED115.CO, LED116.CI
unnamed: LED118.DO, LED119.DI
unnamed: LED118.CO, LED119.CI
unnamed: LED119.DO, LED120.DI
unnamed: LED119.CO, LED120.CI
unnamed: LED120.DO, LED121.DI
unnamed: LED120.CO, LED121.CI
unnamed: LED117.DO, LED118.DI
unnamed: LED117.CO, LED118.CI
unnamed: LED121.DO, LED122.DI
unnamed: LED121.CO, LED122.CI
unnamed: LED122.DO, LED123.DI
unnamed: LED122.CO, LED123.CI
unnamed: LED123.DO, LED124.DI
unnamed: LED123.CO, LED124.CI
unnamed: LED124.DO, LED125.DI
unnamed: LED124.CO, LED125.CI
unnamed: LED125.DO, LED126.DI
unnamed: LED125.CO, LED126.CI
unnamed: LED126.DO, LED127.DI
unnamed: LED126.CO, LED127.CI
unnamed: LED127.DO, LED128.DI
unnamed: LED127.CO, LED128.CI
unnamed: LED128.DO, LED129.DI
unnamed: LED128.CO, LED129.CI
unnamed: LED98.DI, U$15.3 (1Y)
unnamed: LED98.CI, U$15.6 (2Y)
unnamed: LED103.DI, U$15.8 (3Y)
unnamed: LED103.CI, U$15.11 (4Y)
unnamed: LED109.DI, U$16.3 (1Y)
unnamed: LED109.CI, U$16.6 (2Y)
unnamed: LED117.DI, U$16.8 (3Y)
unnamed: LED117.CI, U$16.11 (4Y)

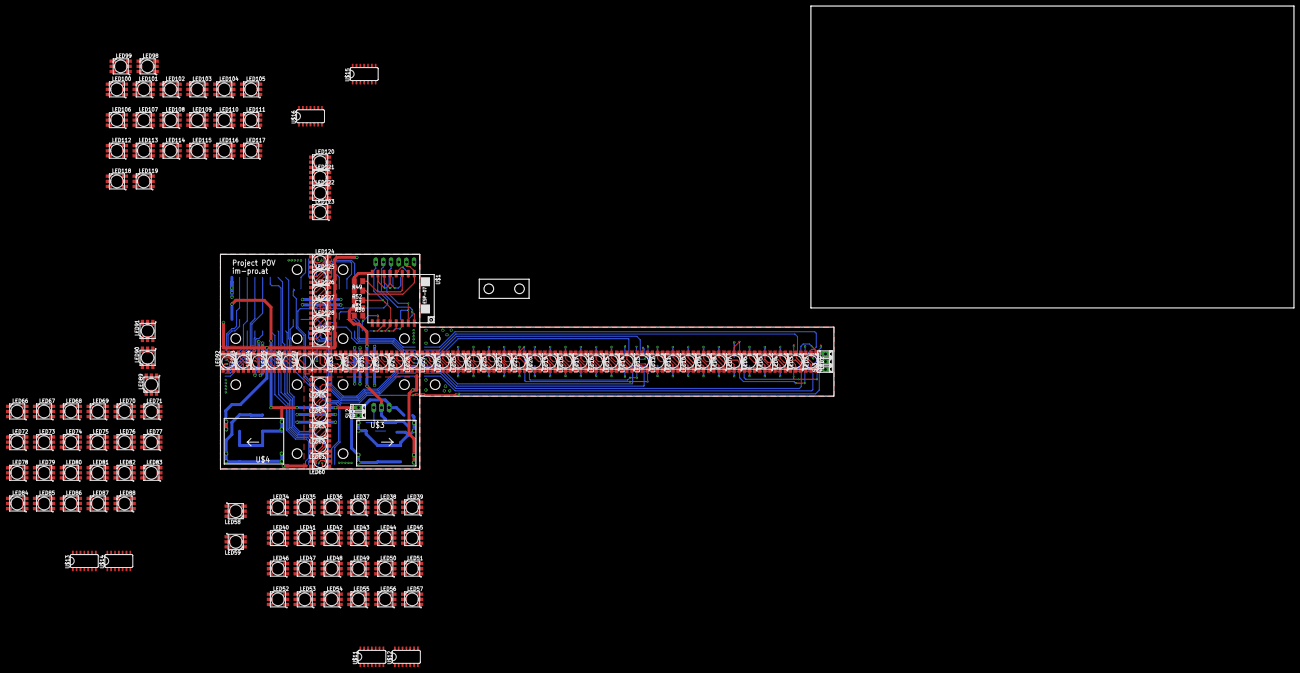
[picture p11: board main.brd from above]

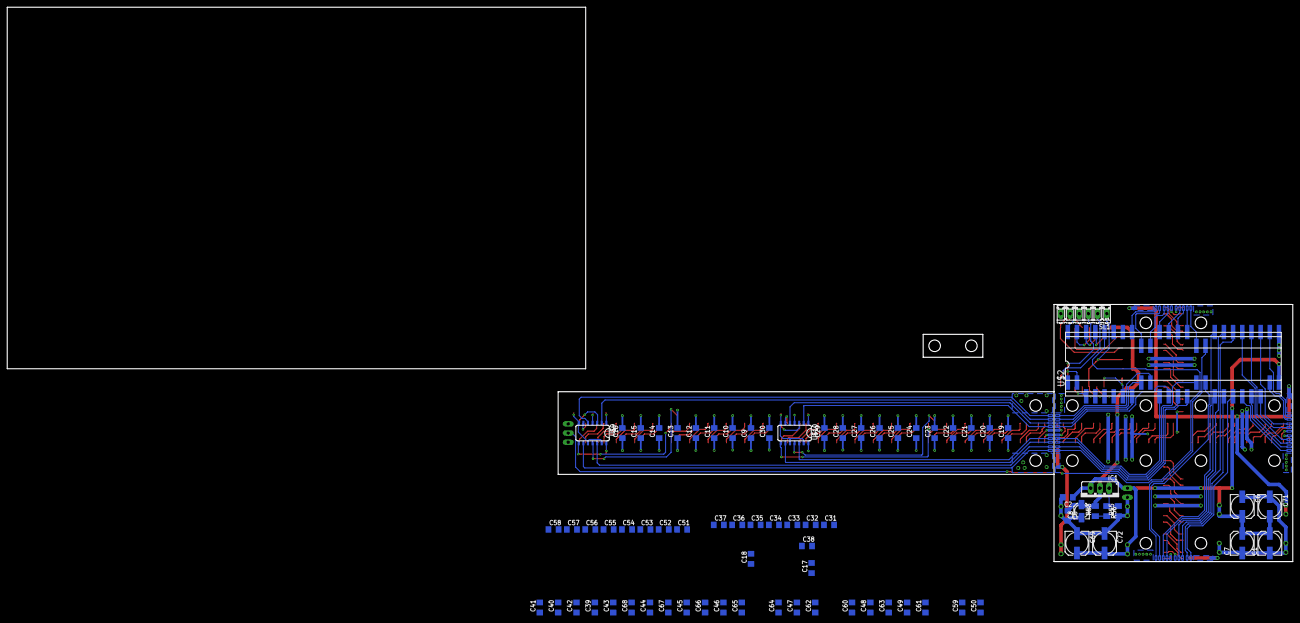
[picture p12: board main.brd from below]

Board: 2 copper layers, 355.6 x 153.3 mm, 222 parts (77 on the bottom side), 311 nets.

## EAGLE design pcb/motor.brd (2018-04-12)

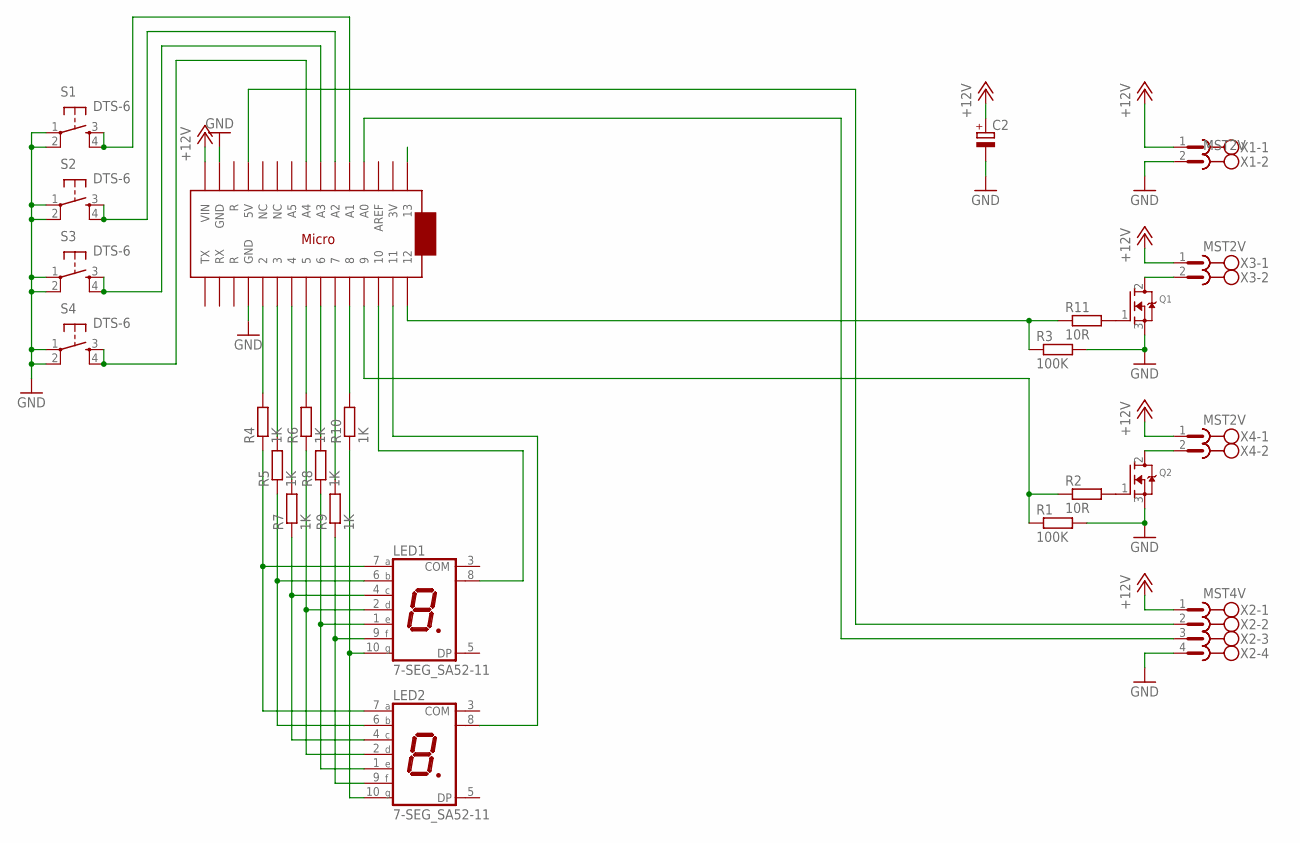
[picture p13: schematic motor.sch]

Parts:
C2: CPOL-EUE5-8.5; E5-8,5
LED1, LED2: 7-SEG_SA52-11; SA52-11
Q1, Q2: MOSFET-NGDS_TO220V; TO220V
R1, R3: 100K; M1206
R2, R11: 10R; M1206
R4, R5, R6, R7, R8, R9, R10: 1K; M1206
S1, S2, S3, S4: DTS-6
U$2: ARDUINOMICRO_NEW; ARDUINOMIRCO_NEW
X1, X3, X4: MST2V; MSTBV2
X2: MST4V; MSTBV4

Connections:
+12V: C2.+, U$2.P$20 (VIN), X1.1, X2.1, X3.1, X4.1
GND: C2.-, Q1.3 (S), Q2.3 (S), R1.2, R3.2, S1.1, S1.2, S2.1, S2.2, S3.1, S3.2, S4.1, S4.2, U$2.P$12 (GND), U$2.P$21 (GND), X1.2, X2.4
unnamed: Q2.2 (D), X4.2
unnamed: Q1.2 (D), X3.2
unnamed: Q1.1 (G), R11.2
unnamed: S4.3, S4.4, U$2.P$27 (A4)
unnamed: R1.1, R2.1, U$2.P$4 (9)
unnamed: Q2.1 (G), R2.2
unnamed: U$2.P$31 (A0), X2.3
unnamed: R4.2, U$2.P$11 (2)
unnamed: LED1.10 (G), LED2.10 (G), R10.1
unnamed: R5.2, U$2.P$10 (3)
unnamed: LED1.9 (F), LED2.9 (F), R9.1
unnamed: R7.2, U$2.P$9 (4)
unnamed: R6.2, U$2.P$8 (5)
unnamed: R8.2, U$2.P$7 (6)
unnamed: R9.2, U$2.P$6 (7)
unnamed: R10.2, U$2.P$5 (8)
unnamed: U$2.P$23 (5V), X2.2
unnamed: S3.3, S3.4, U$2.P$28 (A3)
unnamed: R3.1, R11.1, U$2.P$1 (12)
unnamed: S2.3, S2.4, U$2.P$29 (A2)
unnamed: S1.3, S1.4, U$2.P$30 (A1)
unnamed: LED1.1 (E), LED2.1 (E), R8.1
unnamed: LED1.2 (D), LED2.2 (D), R6.1
unnamed: LED1.4 (C), LED2.4 (C), R7.1
unnamed: LED1.6 (B), LED2.6 (B), R5.1
unnamed: LED1.7 (A), LED2.7 (A), R4.1
unnamed: LED1.8 (COM), U$2.P$3 (10)
unnamed: LED2.8 (COM), U$2.P$2 (11)



Board: 2 copper layers, 44.4 x 77.8 mm, 25 parts (11 on the bottom side), 30 nets.

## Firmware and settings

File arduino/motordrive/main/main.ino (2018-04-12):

#include <AutoPID.h>

#define NUM1_EN 10
#define NUM2_EN 11

#define NUM_NON 0
#define NUM_A 2
#define NUM_B 3
#define NUM_C 4
#define NUM_D 5
#define NUM_E 6
#define NUM_F 7
#define NUM_G 8
#define NUM_DOT 9

#define BTN1 A1
#define BTN2 A2
#define BTN3 A3
#define BTN4 A4

#define TRIGGER A0

#define LED 12
#define MOTOR 9

byte segments[] ={NUM_A  ,NUM_B  ,NUM_C  ,NUM_D  ,NUM_E  ,NUM_F  ,NUM_G};
byte numbers[][7]= {  
                        {NUM_A  ,NUM_B  ,NUM_C  ,NUM_D  ,NUM_E  ,NUM_F  ,NUM_NON}, // 0
                        {NUM_NON,NUM_B  ,NUM_C  ,NUM_NON,NUM_NON,NUM_NON,NUM_NON}, // 1
                        {NUM_A  ,NUM_B  ,NUM_NON,NUM_D  ,NUM_E  ,NUM_NON,NUM_G  }, // 2
                        {NUM_A  ,NUM_B  ,NUM_C  ,NUM_D  ,NUM_NON,NUM_NON,NUM_G  }, // 3
                        {NUM_NON,NUM_B  ,NUM_C  ,NUM_NON,NUM_NON,NUM_F  ,NUM_G  }, // 4
                        {NUM_A  ,NUM_NON,NUM_C  ,NUM_D  ,NUM_NON,NUM_F  ,NUM_G  }, // 5
                        {NUM_A  ,NUM_NON,NUM_C  ,NUM_D  ,NUM_E  ,NUM_F  ,NUM_G  }, // 6
                        {NUM_A  ,NUM_B  ,NUM_C  ,NUM_NON,NUM_NON,NUM_NON,NUM_NON}, // 7
                        {NUM_A  ,NUM_B  ,NUM_C  ,NUM_D  ,NUM_E  ,NUM_F  ,NUM_G  }, // 8
                        {NUM_A  ,NUM_B  ,NUM_C  ,NUM_NON,NUM_NON,NUM_F  ,NUM_G  }, // 9
                        {NUM_A  ,NUM_B  ,NUM_C  ,NUM_NON,NUM_E  ,NUM_F  ,NUM_G  }, // A
                        {NUM_NON,NUM_NON,NUM_C  ,NUM_D  ,NUM_E  ,NUM_F  ,NUM_G  }, // B
                        {NUM_NON,NUM_NON,NUM_NON,NUM_D  ,NUM_E  ,NUM_NON,NUM_G  }, // C
                        {NUM_NON,NUM_B  ,NUM_C  ,NUM_D  ,NUM_E  ,NUM_NON,NUM_G  }, // D
                        {NUM_A  ,NUM_NON,NUM_NON,NUM_D  ,NUM_E  ,NUM_F  ,NUM_G  }, // E
                        {NUM_A  ,NUM_NON,NUM_NON,NUM_NON,NUM_E  ,NUM_F  ,NUM_G  }, // F
                   }; 


byte temp;
byte num1, num2;
unsigned long num_last_number_update;
byte num_last=0;

void update_num(){
  if(millis()-num_last_number_update > 10 ){
    num_last_number_update = millis();
    byte akt_number= 0;
    if(num_last==0){
      num_last=1;
      akt_number=num2;
      digitalWrite(NUM1_EN, HIGH);
    }
    else{ 
      num_last=0;    
      akt_number=num1;
      digitalWrite(NUM2_EN, HIGH);
    }

    for (int i =0;i<7;i++){
      digitalWrite(segments[i], LOW);      
    }
    if(akt_number<=15){
      for (int i =0;i<7;i++){
        if(numbers[akt_number][i]!=0)
          digitalWrite(numbers[akt_number][i], HIGH);      
      }
    }
    if(num_last==0){
      digitalWrite(NUM1_EN, LOW);
    }
    else{
      digitalWrite(NUM2_EN, LOW);
    }
  }
}

byte BTNs[] {BTN1,BTN2,BTN3,BTN4};
unsigned long btn_last_aktivity=0;
int btn_last_pressed = -1;
void update_btn(){
  if(millis() - btn_last_aktivity > 20 ){
    if(btn_last_pressed == -1){
      //search for new button press
      for(int i=0;i<4;i++){
        if(digitalRead(BTNs[i])==LOW){
          btn_last_pressed=i;
          btn_last_aktivity = millis();
          btn_pressed(btn_last_pressed+1);
        }
      }
    }
    else{
      btn_last_aktivity = millis();
      if(digitalRead(BTNs[btn_last_pressed])!=LOW){
        btn_last_pressed=-1;
      }
    }
  }
}

void pciSetup(byte pin)
{
    *digitalPinToPCMSK(pin) |= bit (digitalPinToPCMSKbit(pin));  // enable pin
    PCIFR  |= bit (digitalPinToPCICRbit(pin)); // clear any outstanding interrupt
    PCICR  |= bit (digitalPinToPCICRbit(pin)); // enable interrupt for the group
}

volatile double pid_in, pid_out, pid_set;
AutoPID myPID(&pid_in, &pid_set, &pid_out, 0, 255, 10, 10, 0);


void setup() {
  Serial.begin(115200);

  // put your setup code here, to run once:
  pinMode(NUM1_EN, OUTPUT); 
  pinMode(NUM2_EN, OUTPUT); 
  pinMode(NUM_A, OUTPUT); 
  pinMode(NUM_B, OUTPUT); 
  pinMode(NUM_C, OUTPUT); 
  pinMode(NUM_D, OUTPUT); 
  pinMode(NUM_E, OUTPUT); 
  pinMode(NUM_F, OUTPUT); 
  pinMode(NUM_G, OUTPUT); 
  pinMode(NUM_DOT, OUTPUT); 

  pinMode(BTN1, INPUT_PULLUP);
  pinMode(BTN2, INPUT_PULLUP);
  pinMode(BTN3, INPUT_PULLUP);
  pinMode(BTN4, INPUT_PULLUP);

  pinMode(TRIGGER, INPUT_PULLUP);

  pinMode(MOTOR, OUTPUT);
  digitalWrite(MOTOR, LOW);
  pinMode(LED, OUTPUT);
  digitalWrite(LED, LOW);


  pciSetup(A0);

  myPID.setBangBang(10);
  myPID.setTimeStep(10);
}



volatile unsigned long trigger_last_mil=0;
volatile int trigger_val=-1;
ISR (PCINT1_vect) // handle pin change interrupt for A0 to A5 here
{
  if(digitalRead(A0)== LOW){
    if(trigger_last_mil!=0){
      if(millis()-trigger_last_mil >1000){
        trigger_val=-1;
      }
      else{
        trigger_val=millis()-trigger_last_mil;
      }
    }
    trigger_last_mil= millis();
  }
}  
void update_tigger(){
  //timeout:
  
  cli();               
  if(millis()-trigger_last_mil >1000){
    trigger_last_mil=0;
    trigger_val=-1;
  }
  sei();               
}


int set_rpm = 25;
byte motor_on_off=0;
byte led_on_off=0;
unsigned long motor_on_mil=0;
unsigned long set_last_mil=0;

void btn_pressed(int btn){
  if(btn==1){ //ON OFF MOTOR
    if(motor_on_off==1){
      motor_on_off=0;
    }
    else{
      motor_on_off=1;  
      motor_on_mil=millis();   
    }
  }
  if(btn==2){ //ON OFF LED
    if(led_on_off==1){
      led_on_off=0;
      digitalWrite(LED, LOW);      
    }
    else{
      led_on_off=1;
      digitalWrite(LED, HIGH);            
    }
    
  }
  if(btn==3){ //SET +
    set_rpm++;
    if(set_rpm>60) set_rpm=60;
    set_last_mil= millis();
  }
  if(btn==4){ //SET -
    set_rpm--;
    if(set_rpm<5) set_rpm=5;    
    set_last_mil= millis();
  }
}


int tigger_last=-2;
int akt_rps=100;
void loop() {
  update_num();
  update_btn();
  update_tigger();

  //update time:
  cli();                
  int temp=trigger_val;
  sei();               
  if(temp!=tigger_last){
    tigger_last=temp;
    if(tigger_last==-1){
      akt_rps=0;
      num1=0;   //show 0F
      num2=0;
    }
    else{
      //calc rps
      akt_rps = 1000/tigger_last;
      num1=akt_rps/10;
      if(num1==0) num1=16;
      num2=akt_rps%10;
    }
  }

  if(motor_on_off==0){
      num1=0;   //show 0F
      num2=15;
      tigger_last=-2; 
  }

  //show set for 1 secound
  if(millis()-set_last_mil < 1000){
      num1=set_rpm/10;
      if(num1==0) num1=16;
      num2=set_rpm%10;   
      tigger_last=-2; 
  }

  if(akt_rps==0 and millis()-motor_on_mil >3000){
    motor_on_off=0; // no rotation switch motor off
  }

  //calc pid
  pid_set=set_rpm;
  if(motor_on_off==0){ //simulate high spinning motor => PWM = 0
    pid_in=100;
  }
  else{
    pid_in=akt_rps;
  }
  myPID.run();
  
  static unsigned long timetemp=0;
  if(millis()-timetemp >100){
    timetemp=millis();
    Serial.print(pid_in);
    Serial.print(",");
    Serial.print(pid_set);
    Serial.print(",");
    Serial.println(pid_out);
  }
  analogWrite(MOTOR,pid_out);
    
}

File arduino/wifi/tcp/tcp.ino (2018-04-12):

//CPU frequence 160MHz !!!!!!!!

#include <ESP8266WiFi.h>          //https://github.com/esp8266/Arduino
#include <DNSServer.h>            //Local DNS Server used for redirecting all requests to the configuration portal
#include <ESP8266WebServer.h>     //Local WebServer used to serve the configuration portal
#include <WiFiManager.h>          //https://github.com/tzapu/WiFiManager WiFi Configuration Magic

WiFiServer server(9999);

#define BUFFER_SIZE 1024
uint8_t buffer[BUFFER_SIZE];

void setup() {
  delay(1000);
  
  //  WiFiManager wifiManager;  
  //  wifiManager.autoConnect();

  WiFi.softAP("POV");

  server.begin();

  pinMode(0, OUTPUT); //D0
  pinMode(1, OUTPUT); //D1
  pinMode(2, OUTPUT); //D2
  pinMode(3, OUTPUT); //D3
  pinMode(12, OUTPUT); //D4
  pinMode(13, OUTPUT); //D5
  pinMode(14, OUTPUT); //D6
  pinMode(15, OUTPUT); //D7

  pinMode(4, OUTPUT); //CLK  IS GPIO 5 
  pinMode(5, OUTPUT); //SYNC IS GPIO 4
  pinMode(16, OUTPUT); //data_open
  
}

// the loop function runs over and over again forever
void loop() {
  unsigned long t=0;
  digitalWrite(16, LOW); //data_open

  //if(WiFi.status() != WL_CONNECTED){
  //  ESP.reset();
  //}
  
  WiFiClient client = server.available();
  if (client)
  {
    t=millis();
    client.setNoDelay(1);
    int counter =0;
    volatile byte timout;
    digitalWrite(16, HIGH); //data_open
    while (client.connected())
    {
      if (client.available()){
        t=millis();
        int resived = client.read(buffer,BUFFER_SIZE);
        for (int i=0; i<resived; i++){
          GPOC = 0x0010; // CLK falling edge
          for(timout=0;timout<10;timout++); //Sleep 2µs
          GPOC = 0xF03F;
          if (counter==0) {
            GPOS = 0x0020; //SYNC                            
          }
          GPOS = buffer[i]&0x000F; //D0-3
          GPOS = ((buffer[i]<<8)&0xF000)| 0x0010; //D4-7 + CLK rising edge       
          for(timout=0;timout<10;timout++); //Sleep 2µs
          counter++;
          if(counter>=(131*131-19*19*4+1)*3/2){
            counter=0;     
          }
        }
      }
      if(t+1000<=millis()){
        break;
      }
    }    
    client.stop();  
  }
}

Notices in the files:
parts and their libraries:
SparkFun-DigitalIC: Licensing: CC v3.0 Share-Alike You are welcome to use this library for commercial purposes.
